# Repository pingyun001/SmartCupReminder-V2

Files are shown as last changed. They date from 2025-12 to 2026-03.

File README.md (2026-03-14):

<!-- 这是一张图片，ocr 内容为： -->
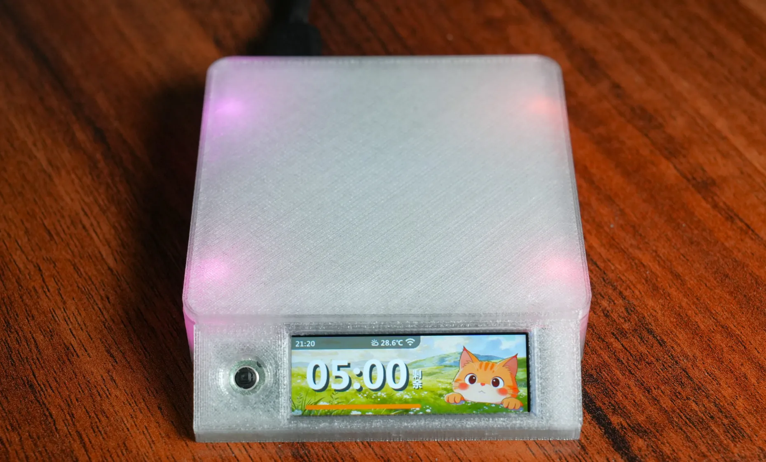
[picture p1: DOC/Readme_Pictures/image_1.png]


# 1、概览：
## 1.1、导览：
如果您拿到的是**成品杯垫**，直接查看章节1.概览、章节2开箱使用即可。无需查看其余章节。

如果您是电子爱好者，希望**从0开始动手制造**该杯垫，请阅读其余部分。

## 1.2、功能概览：
基础功能：

+ 放下水杯，杯垫自动进行一定时间倒计时，时间到，提醒用户喝水
+ 放下水杯、时间到了、拿走水杯 等语音播报
+ 可调节倒计时时间、灯光亮度、声音大小、灯光效果
+ 丰富的RGB灯光效果，支持 彩虹、蜡烛、星夜、纯白 四种灯效
+ 夜间模式，晚11点到早7点之间自动降低屏幕亮度和灯光亮度
+ 杯垫内集成温度传感器，可监测自身温度
+ 支持模拟U盘，可方便地更新语音文件（WAV文件）或更新固件（update.bin文件）

wifi联网功能：

> 本杯垫集成了wifi功能，可连接网络，实现时间自动同步和天气信息自动同步
>

+ 可连接指定2.4G wifi网络（需通过U盘模式 在setting.txt中存入wifi名称和密码）
+ 可指定当前城市，支持拼音（需通过U盘模式 在setting.txt中存入城市，例如北京：beijing）
+ 可自动获取当前城市的天气，温度，湿度，以及未来两天的天气预报
+ 可自动获取网络时间（24小时制）
+ 语音拓展功能：
    - 可根据当前时间，自动连携播放时间语音（早、中、晚）
    - 可根据当前天气，自动连携播放天气语音（晴天、下雨、下雪）

# 2、开箱使用
## 2.1、外观介绍
+ 摇杆：可向上下左右拨动，以及向中心按下，共5个方向。具体含义如下：
    - 上下左右：灵活切换各界面，选择选项卡等
    - 中：选择
+ 彩色屏幕：
    - 可显示倒计时时间、天气预报、设置等
+ 水杯放置区域：
    - 用于放置水杯，可被水杯的重量轻微下压1mm。
    - <font style="color:#DF2A3F;">注意！</font>整体材料为3D打印材料，怕热，请勿让水杯放置区域温度高于50℃
+ USB-TypeC接口：
    - 杯垫不含电池，需通过该接口供电，推荐供电能力5V 1A
    - 该接口同时作为USB通讯接口，可将杯垫通过该接口+数据线连接电脑后，在杯垫设置中打开U盘模式，即可更新杯垫内wifi密码、语音等。

<!-- 这是一张图片，ocr 内容为： -->
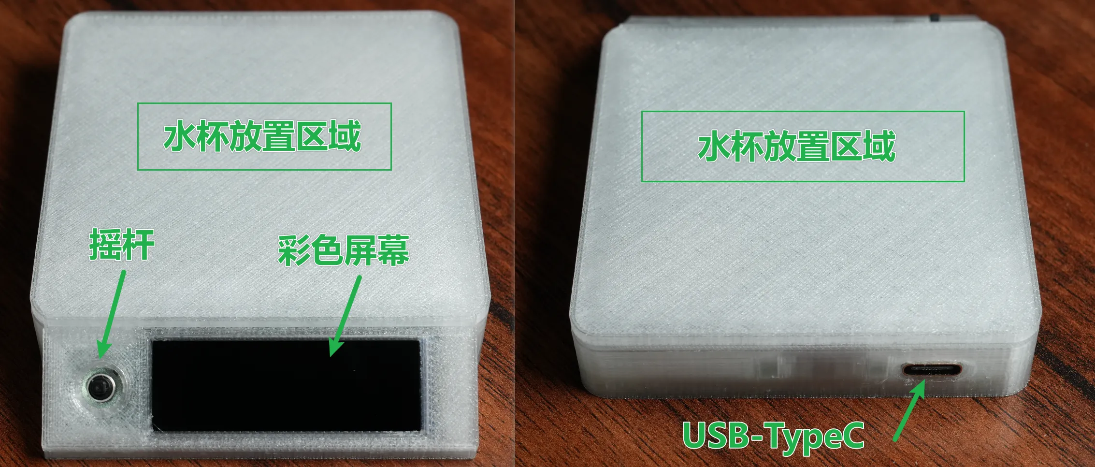
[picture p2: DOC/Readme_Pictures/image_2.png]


## 2.2、界面说明
### 2.2.1、开机自检界面
通过使用TYPE-C数据线连接USB-TypeC接口和电脑，杯垫屏幕点亮，并展示当前初始化进度：

<!-- 这是一张图片，ocr 内容为： -->
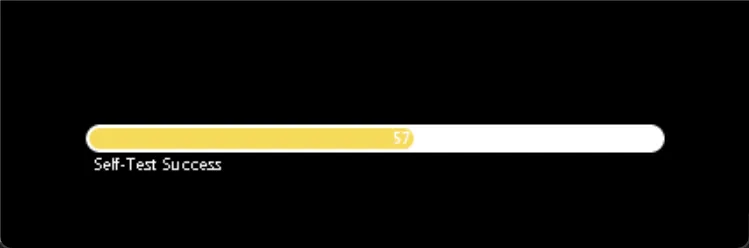
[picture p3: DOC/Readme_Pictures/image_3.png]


其中进度条展示当前开机进度，下方文字展示对应系统自检内容，如果进度条卡死，可根据下方自检内容判断故障原因。

### 2.2.2、主界面
自检完成后，进入主界面，可以看到如下信息：

> **<font style="color:#DF2A3F;">注！标星号*项需要wifi联网使用</font>**
>

+ 网络时间*：当前时间，可在连接wifi后自动通过网络获取
+ 夜间模式：用于指示当前杯垫是否处于夜间模式，该模式下屏幕和灯光亮度减弱
+ 天气信息*：该图标用于指示是否成功连接天气服务器，若成功连接，则该图标显示，否则隐藏
+ 杯垫温度：该温度由杯垫内部的温度传感器获取
+ wifi状态*：用于指示wifi是否成功连接，成功连接为白色，否则为黄色
+ 剩余时间进度条：用于指示剩余时间占总时间的比例
+ 剩余时间：用于显示剩余时间（格式  分钟：秒）
+ 杯垫状态：共三个表情包，分别对应 无水杯、水杯放下、时间到

<!-- 这是一张图片，ocr 内容为： -->
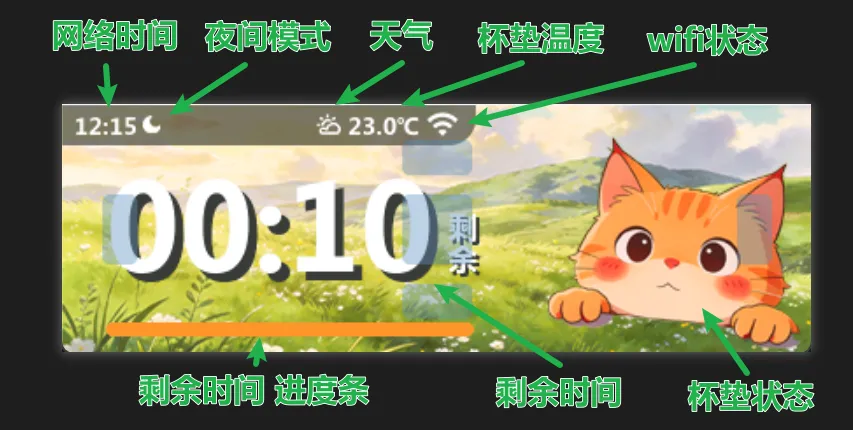
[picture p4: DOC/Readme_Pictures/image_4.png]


---

### 2.2.3、天气界面
在主界面下，可通过摇杆上划，进入天气界面：

> 注！该界面所有内容需联网使用
>

+ 当前城市*：中文显示城市名称，该中文名称由天气服务器返回
+ 今天、明天、后天：指示三天的日期，天气，温度范围，湿度

<!-- 这是一张图片，ocr 内容为： -->
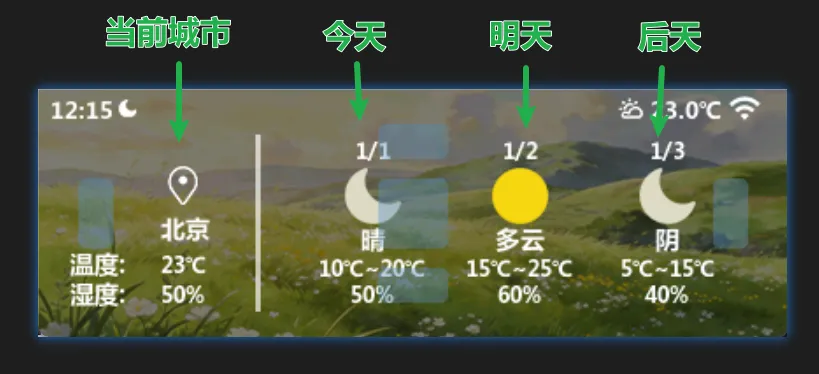
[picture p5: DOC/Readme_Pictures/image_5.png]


### 2.2.4、设置界面
在天气界面，继续上滑（或从主界面下滑，进入设置界面）：

设置界面中，可通过上下左右方向键选择需要的选项，并通过中键确定。左侧为标题，中间为具体选项，右侧为详细说明。

计时界面：

+ 可选择倒计时时间，当前固件支持如下6个常用时间

<!-- 这是一张图片，ocr 内容为： -->
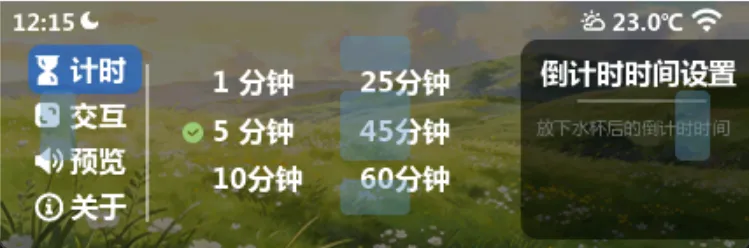
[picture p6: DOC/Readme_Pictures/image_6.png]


---

交互界面：

+ 可选择提示音大小
+ 可选择灯光亮度
+ 可选择灯光种类：
    - 虹：彩虹色效果，所有灯按彩虹色依次渐变过渡
    - 烛：模拟蜡烛效果，淡黄色灯光，亮度忽明忽暗
    - 星：星夜效果，4颗灯随机点亮，颜色随机
    - 白：纯白色效果，该模式灯光不闪烁。无动效

<!-- 这是一张图片，ocr 内容为： -->
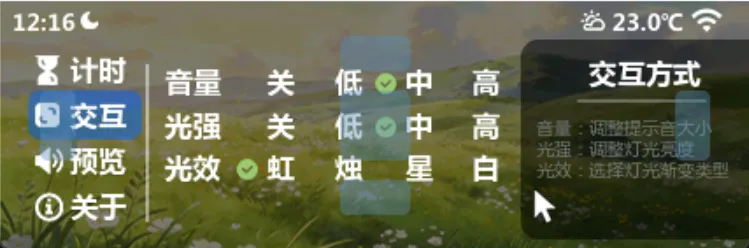
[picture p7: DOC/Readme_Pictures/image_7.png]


---

预览：

+ 用于预览存入杯垫内的音频文件，共有如下10种音频

<!-- 这是一张图片，ocr 内容为： -->
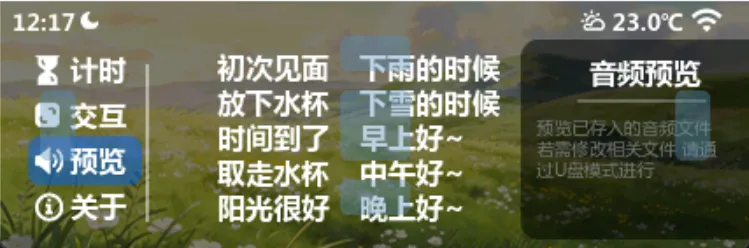
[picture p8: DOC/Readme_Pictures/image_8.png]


---

关于：

+ 可查看当前USB电压，若USB供电不足，会弹出相应提示框
+ JEDEC ID：为板载存储芯片的型号，用于辅助调试
+ WIFI IP：成功连接wifi后，显示杯垫的ip地址
+ 进度U盘 按钮：可将杯垫模拟成U盘，用于更新wifi信息等
+ 重置设备：谨慎操作！该选项会删除杯垫内所有数据（包括音频，字库等），用于杯垫发生极其严重的故障后使用。
+ 右侧 软件版本：显示当前程序的版本号，初始发行版本为V2.0。调试版本为V2.0 DEBUG
+ 右侧 编译时间：显示当前程序的编译时间，Feb 21 2026表示 编译于2026年2月21日

<!-- 这是一张图片，ocr 内容为： -->
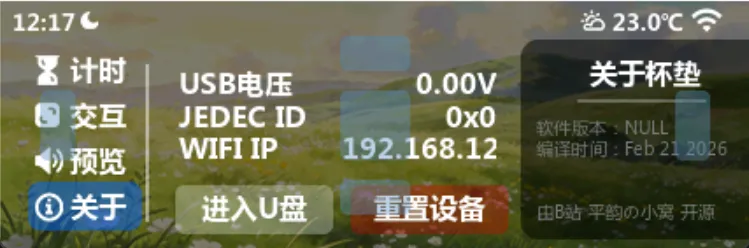
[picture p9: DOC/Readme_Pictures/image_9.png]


---

### 2.2.5、警告&错误
文件系统错误：

若初始化时进度条卡住，且弹出该提示框，表示内部存储芯片内文件损坏，5s后系统将进入U盘模式，可将必要文件拖入该U盘，待复制完成后，为杯垫断电，重新通电即可

<!-- 这是一张图片，ocr 内容为： -->
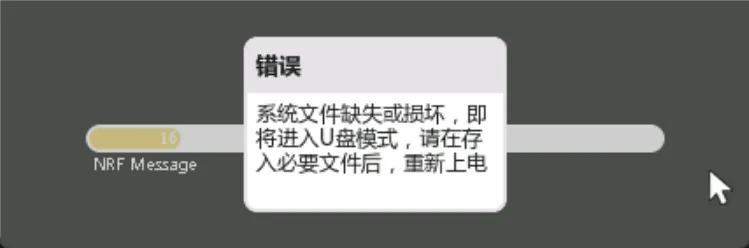
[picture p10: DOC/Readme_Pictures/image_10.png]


---

供电不足：

该提示框可能在任何时候弹出，一旦弹出，表示供电不足（系统会持续检测USB电压，在播放音频等大功耗工况时，可能导致USB电压过低，进而标记供电不足）。

推荐日常使用时，通过手机充电头供电，若使用电脑USB供电，且弹出该提示框，可适当降低音量或LED灯亮度。

<!-- 这是一张图片，ocr 内容为： -->
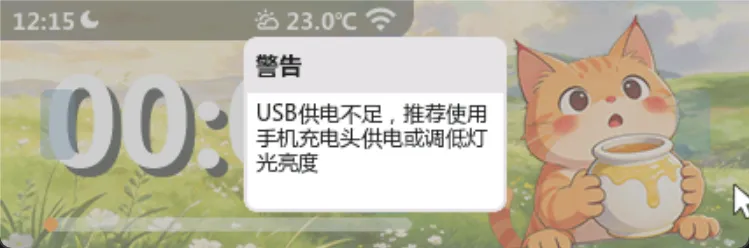
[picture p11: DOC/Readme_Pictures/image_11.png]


---

U盘模式提示：

在点击进入U盘按钮后，弹出该提示框。待提示框消失，即进入U盘模式（此时电脑应该会弹出 叮~ 的USB声音），同时杯垫屏幕、LED等均停止刷新。

在USB传输完成文件后，可在电脑上弹出U盘，之后推荐右滑摇杆，退出U盘模式。

注意！退出U盘模式后，建议断电 并重新上电，以使系统更新各类信息。

<!-- 这是一张图片，ocr 内容为： -->
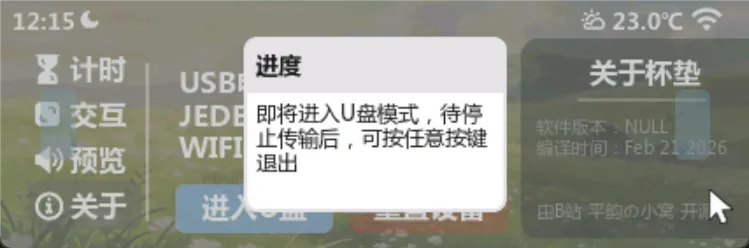
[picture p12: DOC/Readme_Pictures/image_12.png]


---

重置系统：

在点击重置设备按钮后，弹出该提示框。

<!-- 这是一张图片，ocr 内容为： -->
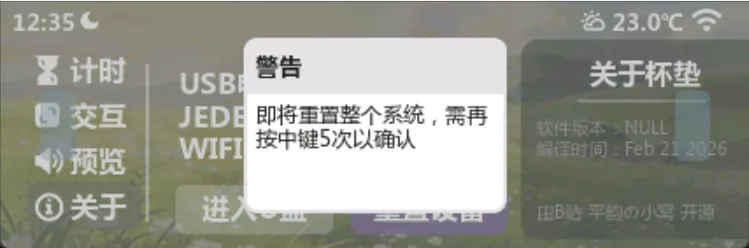
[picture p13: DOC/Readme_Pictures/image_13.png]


再次按5下中键，弹出第二个提示框，待该提示框消失，杯垫将删除所有用户文件（音频，配置信息等）

<!-- 这是一张图片，ocr 内容为： -->
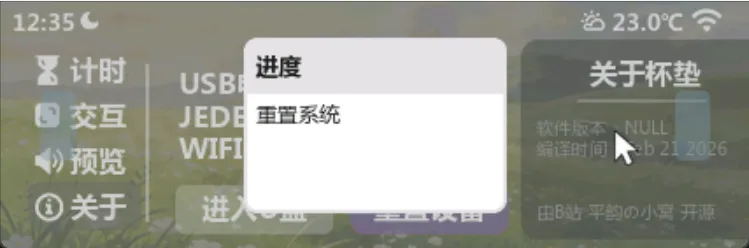
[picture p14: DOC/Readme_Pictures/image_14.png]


## 2.3、修改WIFI信息&连接网络
将杯垫通过USB线连接电脑，点击设置界面中 进入U盘按钮：

<!-- 这是一张图片，ocr 内容为： -->
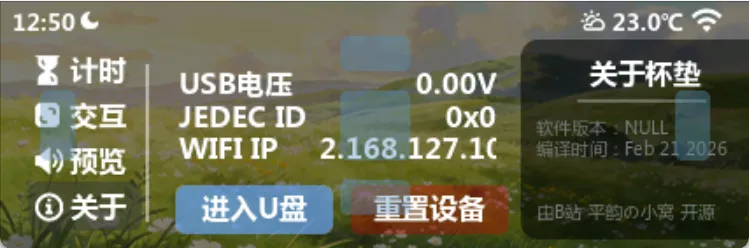
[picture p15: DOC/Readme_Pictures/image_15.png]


待提示框消失，打开电脑，可以看到多了一个U盘：

<!-- 这是一张图片，ocr 内容为： -->


打开该U盘，可以看到如下内容：

<!-- 这是一张图片，ocr 内容为： -->
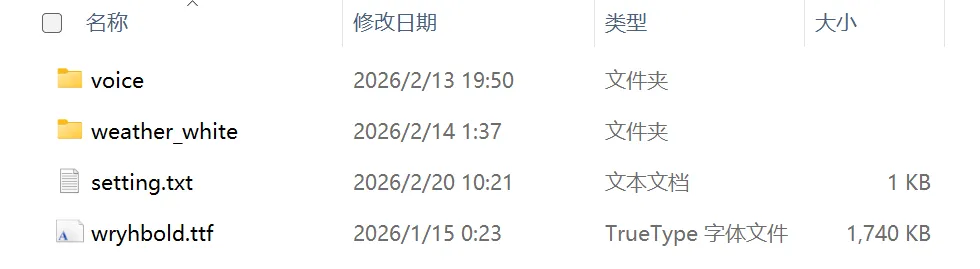
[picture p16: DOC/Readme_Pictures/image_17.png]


wifi信息等保存在setting.txt文件中，使用windows电脑自带的记事本打开该文件：

第一行为wifi名称，第二行为密码，第三行为城市名字

如下图所示，当前信息为：

+ wifi名称：TP-Link-1234
+ wifi密码：12345678
+ 城市名称：Beijing

<!-- 这是一张图片，ocr 内容为： -->
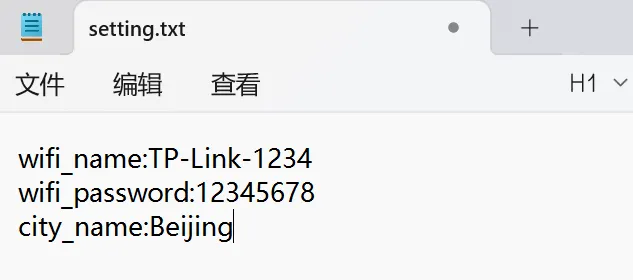
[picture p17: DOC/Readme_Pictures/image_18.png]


按需修改上述信息，

注意！

+ 请勿删除冒号:之前的字符！
+ 请保持每条信息均为新行，不可写到一行中！
+ wifi名称支持中文，需确保右下角编码格式为UTF-8编码

完成修改后，保存该setting.txt文件（可按键盘快捷吗Ctrl + S或记事本左上角 文件->保存）

保存后，从电脑端弹出U盘，为杯垫断电，重新通电，待重新开机，等待30秒左右，杯垫将成功连接wifi并更新天气信息。

## 2.4、更新固件
> 杯垫内置了bootloader，可自动识别Flash中的新固件并完成自动更新。该功能适用于定制主题固件的更新

请进行如下操作：
1. 确保杯垫软件版本号为V2.1及以后版本，若为V2.0，请参考3.5章节烧录二合一固件
2. 通过设置使杯垫进入U盘模式
3. 在路径 SmartCupReminder-V2\SOFTWARE\RELEASE_FIRMWARE下寻找你心仪的固件，该固件文件后缀必须为.bin格式
4. 将心仪固件，重命名为update.bin，并放入杯垫的U盘中，等待文件传输完成（大约1分钟，较慢，请耐心等待）
5. 杯垫断电，重新上电，待杯垫开机，杯垫将自动识别update.bin，若成功识别，左上角LED灯变为黄色，此时请等待杯垫完成固件更新
6. 大约2分钟后，更新完成，左上角LED灯变为绿色，杯垫完成固件更新，并自动删除update.bin文件，之后将自动运行新固件
7. 若中途失败，杯垫将亮红灯（或5分钟以上无响应），可重复上述步骤，若无效，请参考3.5章节通过BOOT按钮进行固件恢复

注意：
杯垫升级过程中，非必要尽量不要断电，以免造成损坏。（虽然bootloader中已经编写了完善的断电重更新机制，但是仍然建议不要随意断电）

# 3、复刻指南
本章节适用于从零制造的极客&电子爱好者，若您直接使用成品杯垫，可不看该章节。

## 3.1、获取工程
工程托管于GitHub：[https://github.com/pingyun001/SmartCupReminder-V2](https://github.com/pingyun001/SmartCupReminder-V2)

内含UI界面设计，硬件原理图，软件源码，机械结构等设计稿

推荐直接通过git克隆到本地即可。

如果电脑没有git环境，也可以直接下载压缩包：

<!-- 这是一张图片，ocr 内容为： -->
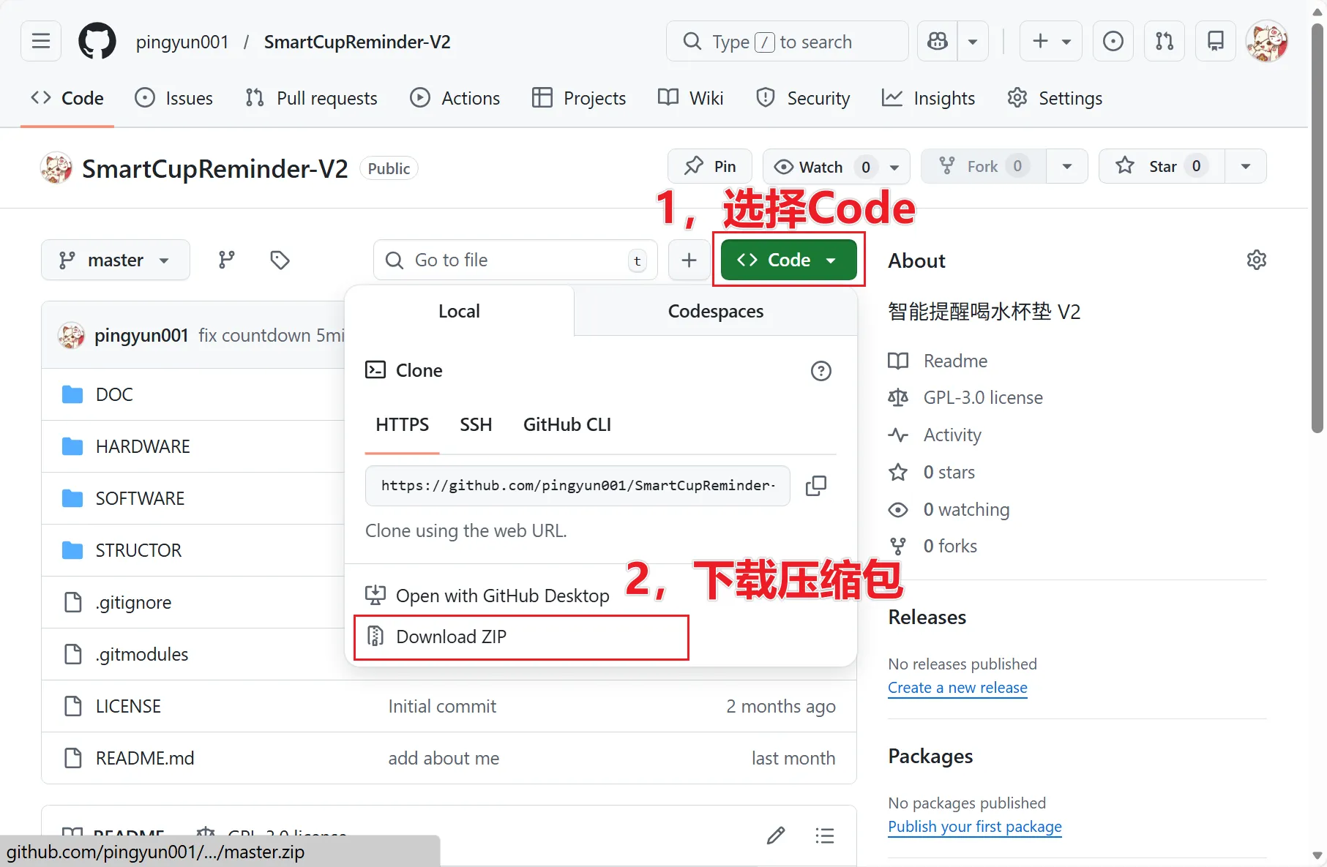
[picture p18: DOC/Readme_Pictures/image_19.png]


## 3.2、硬件焊接
> 默认您已经熟练掌握电路板下单，贴片元器件焊接等技能。
>

自行下单PCB板，注意板厚1.6mm，并完成焊接，焊接完成成品如下：

<!-- 这是一张图片，ocr 内容为： -->
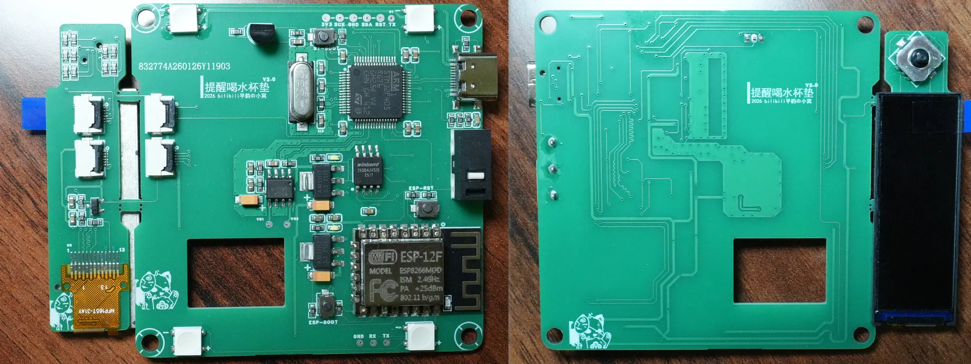
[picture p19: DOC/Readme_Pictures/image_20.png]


推荐优先焊接贴片原件，最后焊接屏幕。

屏幕焊接时，事先在屏幕背面贴好双面胶，并按如下方式对齐，粘贴后，弯折排线，完成焊接

<!-- 这是一张图片，ocr 内容为： -->
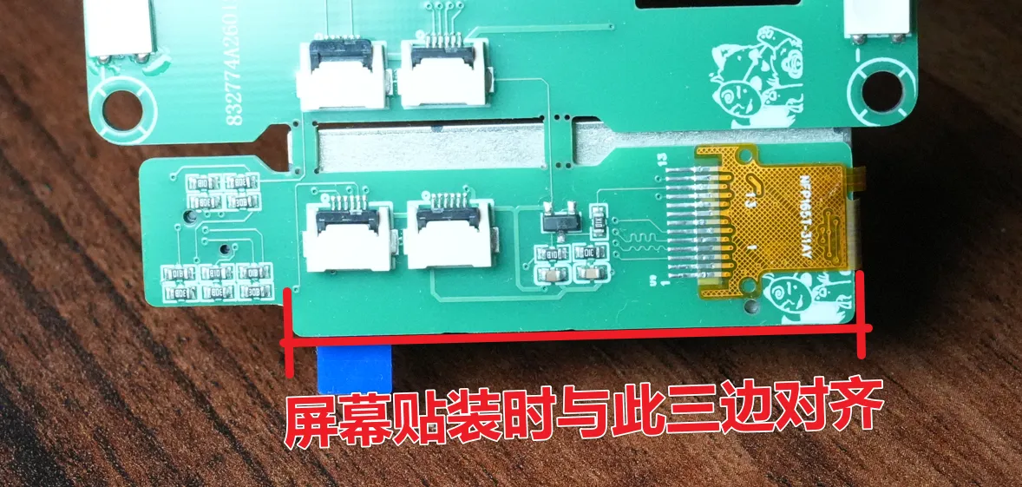
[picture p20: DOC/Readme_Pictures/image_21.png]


## 3.3、机械结构预组装
> 默认您已经熟练掌握3D打印，且有相关打印设备或条件
>

从工程中找到相关3D结构件并打印，共有三个结构件

> 位于路径：\SmartCupReminder-V2\STRUCTOR\打印件
>

推荐直接打印3MF后缀的三个文件
<!-- 这是一张图片，ocr 内容为： -->
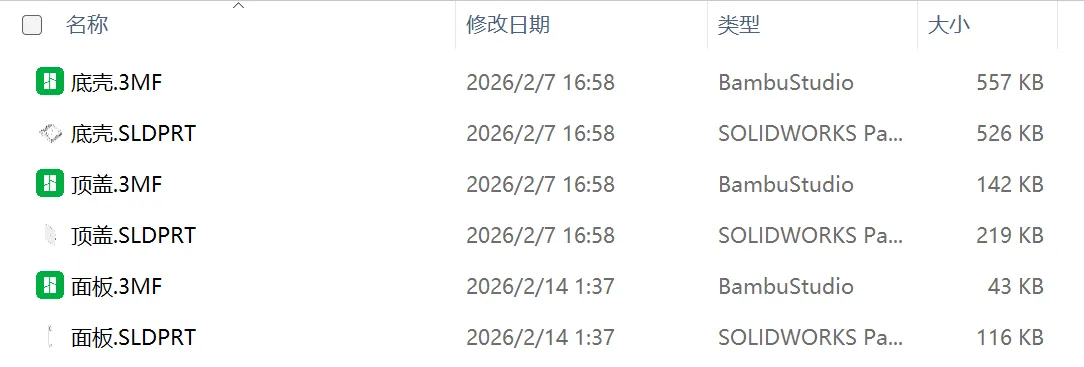
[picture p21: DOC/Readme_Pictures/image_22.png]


完成后如下：

<!-- 这是一张图片，ocr 内容为： -->
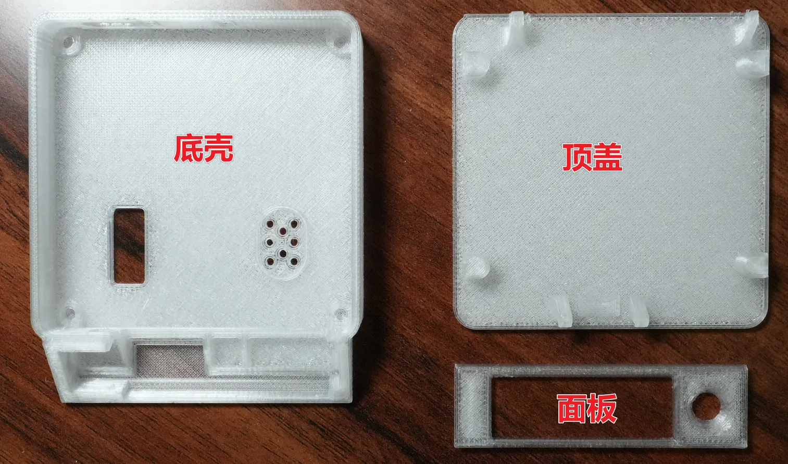
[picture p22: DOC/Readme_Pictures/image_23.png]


完成打印后，拆除必要的支撑，将PCB掰开（分离为底板和屏幕按键子板）后，

按如下步骤进行装配：

<!-- 这是一张图片，ocr 内容为： -->
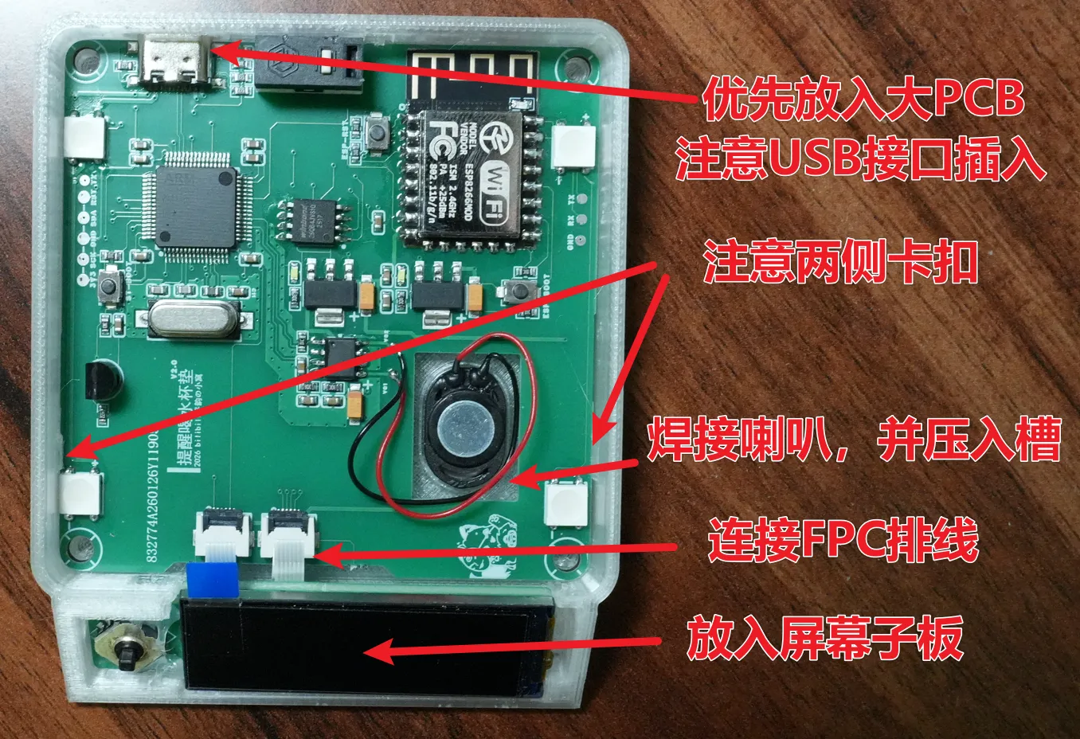
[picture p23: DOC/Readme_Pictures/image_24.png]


## 3.4、ESP8266固件下载
> 固件和源码均位于路径：SmartCupReminder-V2\SOFTWARE\ESP8266_WIFI_WEATHER

可通过传统arduino IDE下载，或通过ESP Tools下载，网上教程非常多，此次不过多介绍。

特别注意！建议使用CH340或CP2102等硬件USB转串口模块进行程序下载。不要使用ST-Link等软件模拟的串口。

按住ESP-BOOT后，为PCB上电，连接ESP下载串口，下载固件即可。

<!-- 这是一张图片，ocr 内容为： -->
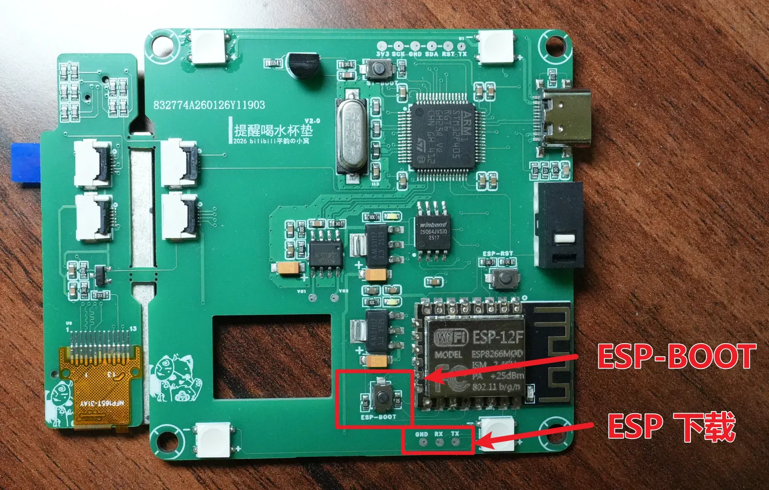
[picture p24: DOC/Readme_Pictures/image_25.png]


## 3.5、STM32固件烧录
> 固件位于路径：SmartCupReminder-V2\SOFTWARE\RELEASE_FIRMWARE

推荐电脑安装STM32CubeProgrammer软件：

<!-- 这是一张图片，ocr 内容为： -->
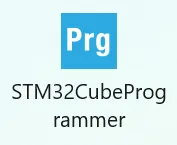
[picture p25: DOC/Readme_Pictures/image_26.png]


并烧录二合一固件Hex，该Hex中已经合并了Bootloader和App固件，无需单独烧录Bootloader。

> 固件位于路径SmartCupReminder-V2\SOFTWARE\RELEASE_FIRMWARE\V2.1\F405_Release_Merged.hex

<!-- 这是一张图片，ocr 内容为： -->
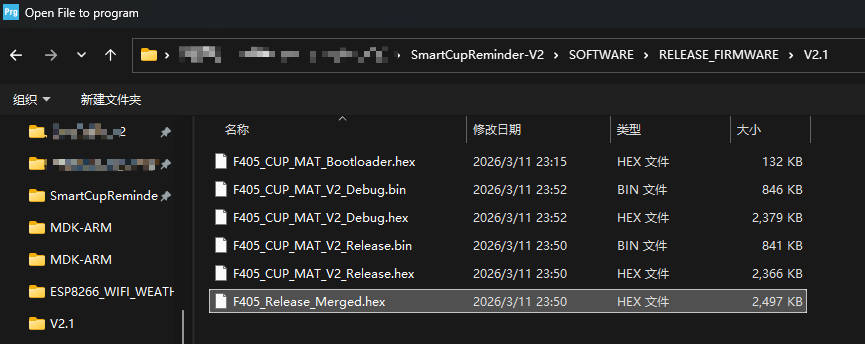
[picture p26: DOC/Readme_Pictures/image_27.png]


推荐使用USB数据线连接PCB板和CubeProgrammer软件，如下图，保持按住BOOT按钮，插入数据线到电脑

<!-- 这是一张图片，ocr 内容为： -->
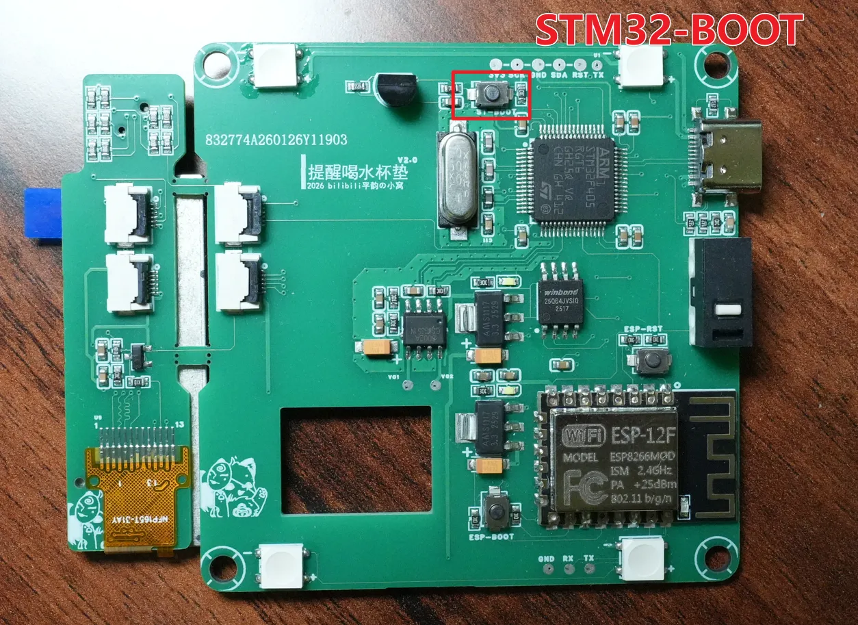
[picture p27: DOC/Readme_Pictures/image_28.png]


可以在CubeProgrammer软件中搜索到STM32芯片，搜索到后，点击连接按钮。

<!-- 这是一张图片，ocr 内容为： -->
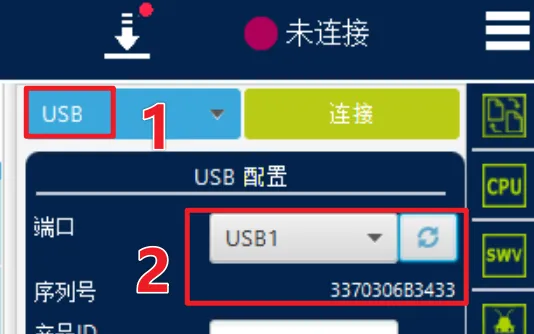
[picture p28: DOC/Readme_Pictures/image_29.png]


成功连接后，下图1处显示已连接，在2处选择上述Hex文件，并点3 开始烧录

<!-- 这是一张图片，ocr 内容为： -->
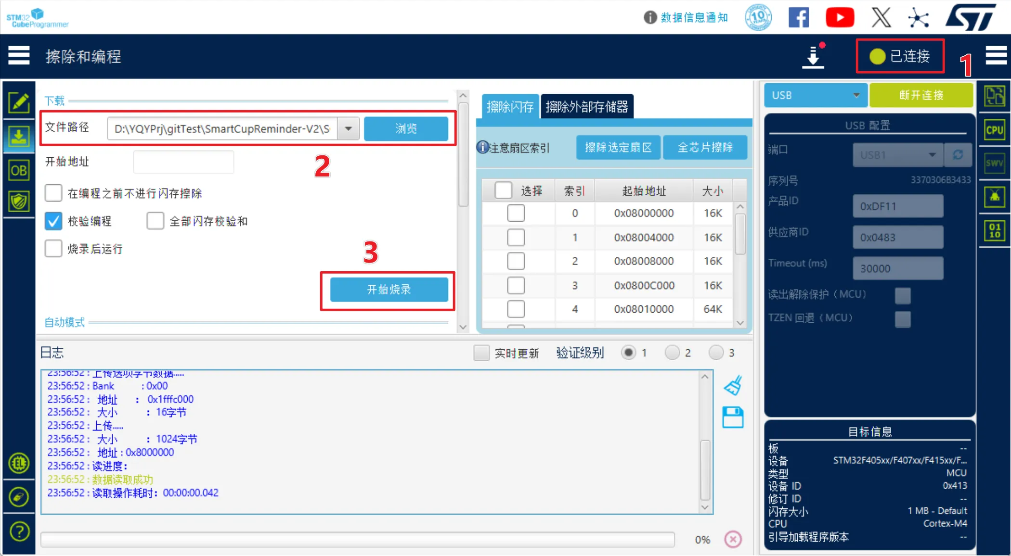
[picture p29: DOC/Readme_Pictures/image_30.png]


待进度条跑完即可。

如果USB方式无法下载，则需通过ST-Link、JLink等，通过SWD接口进行下载

> 由于STM32F4系列芯片的USB IP缺陷，以及板子USB焊接质量问题，可能有概率无法通过USB DFU连接（电脑弹出未识别的USB设备提示框），此时需要通过SWD接口下载程序
>

SWD接口位置如图，按线序连线即可，并连接板子，后续操作步骤同USB

连接ST-Link SWD接口到PCB板，推荐按如下方式接线：

左侧为ST-Link接口，右侧为PCB接口：
- 3V3   <---> 3V3
- SWCLK <---> SCK
- GND   <---> GND
- SWDIO <---> SDA
- RESET <---> RST

同时，建议断开USB供电，全板仅通过ST-Link提供STM32F4所需的3.3V电源

完成连接后，将ST-Link插入电脑，打开STM32CubeProgrammer软件，选择ST-Link模式，点击Connect按钮，选择下载的固件文件，点击Program按钮，等待下载完成。

<!-- 这是一张图片，ocr 内容为： -->
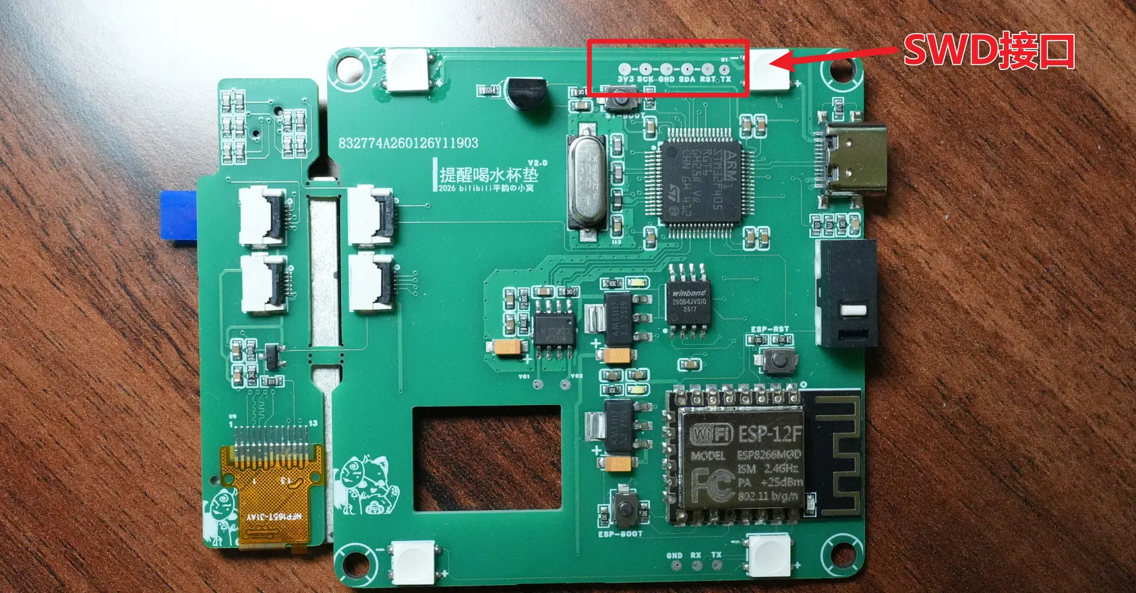
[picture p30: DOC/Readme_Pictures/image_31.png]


## 3.6、U盘文件下载
完成ESP8266和STM32固件烧录后，使用USB线连接杯垫和电脑，杯垫会进行开机自检，检测到文件缺失，会进行弹窗，并进入U盘模式

<!-- 这是一张图片，ocr 内容为： -->


此时电脑上会识别到一个U盘，将必要的文件复制入U盘中：

> 位于路径：SmartCupReminder-V2\SOFTWARE\F4_UDISK_RESOURCES
>

该路径共有如下文件/文件夹，含义：

+ voice：必要的音频文件，格式为WAV
+ weather_white：天气小图标文件，用于天气界面的图片显示
+ setting.txt：用于保存wifi名称，wifi密码，城市位置
+ wryhbold.ttf：中文字体库文件，用于UI界面中的中文显示（城市名称等）

<!-- 这是一张图片，ocr 内容为： -->
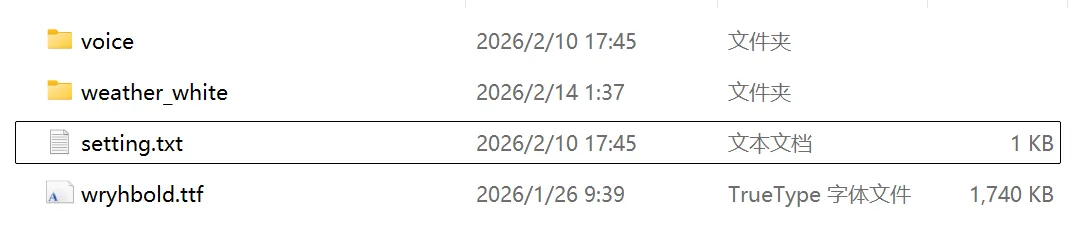
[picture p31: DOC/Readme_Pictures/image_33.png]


其中setting.txt中的内容需要根据自己的wifi名称进行修改，可参考2.3章节。

将这些文件/文件夹全部复制到U盘根目录，完成后，弹出U盘，断电，重新上电，等待自检完成。

成功进入主界面

<!-- 这是一张图片，ocr 内容为： -->
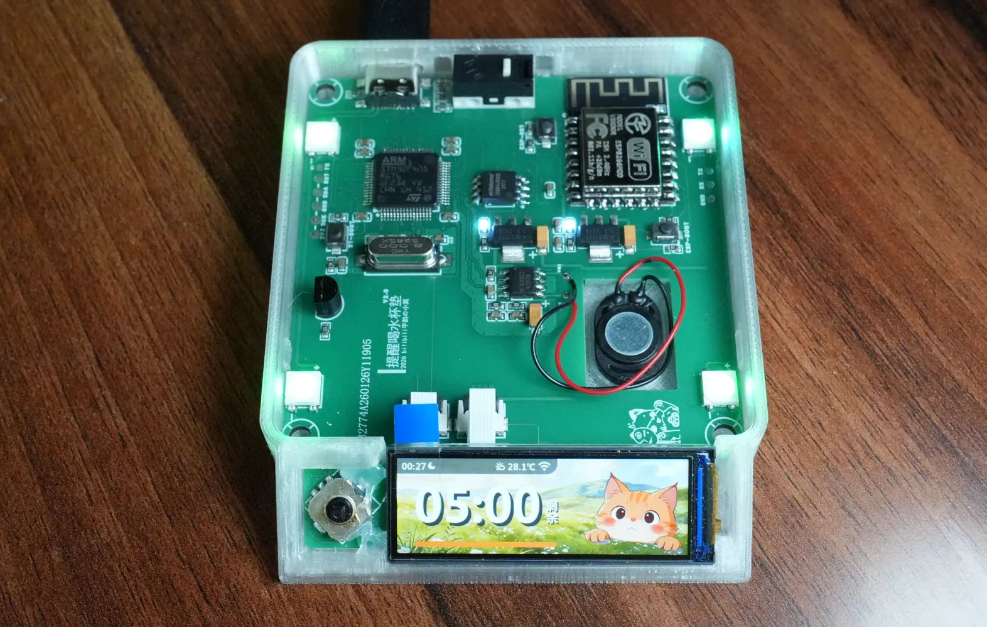
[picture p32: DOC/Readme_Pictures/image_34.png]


## 3.7、机械结构组装
在之前的基础上，安装顶盖：

<!-- 这是一张图片，ocr 内容为： -->
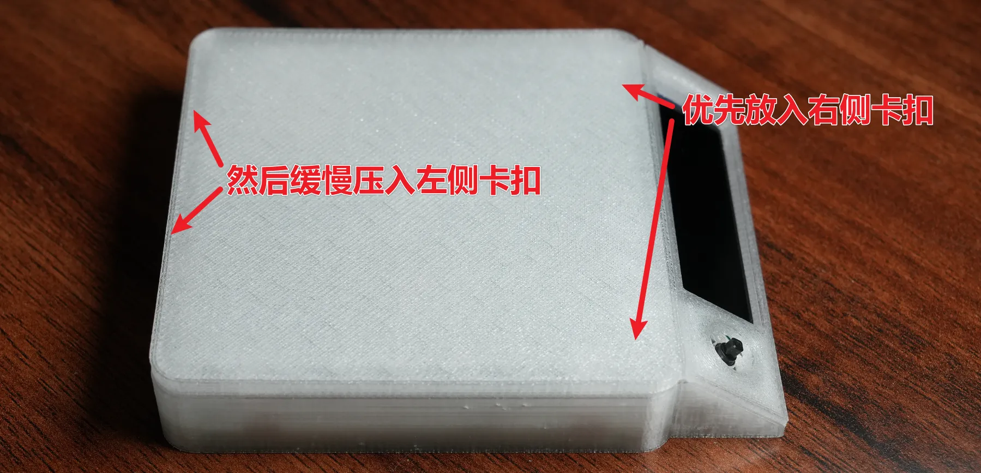
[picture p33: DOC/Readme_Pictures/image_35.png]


同时使用热熔胶粘贴前面板，并完成制作。

此时，您已经成功获取到一个成品杯垫！恭喜~

## 3.8、后续固件升级
> 杯垫内置了bootloader，可自动识别Flash中的新固件并完成固件更新。该功能适用于定制主题固件的更新，以及切换debug和release版本固件。

请进行如下操作：
> 注意！只适用于目前运行V2.1及以上版本固件的杯垫，如果您的杯垫目前运行V2.0版本，则需要手动更新固件，参考上方3.5章节烧录二合一固件。

固件类型说明：
U盘自动更新只支持后缀为.bin的文件，类型包含两种，分别为Debug版和Release版，均位于目录
> SmartCupReminder-V2\SOFTWARE\RELEASE_FIRMWARE\

- F405_CUP_MAT_V2_Debug.bin：包含调试信息（包含屏幕帧率，CPU占用率，串口日志等，可能会轻微影响性能，仅供调试使用）
- F405_CUP_MAT_V2_Release.bin：无调试信息（日常使用版）

自动更新流程：

1. 寻找心仪的固件（固件列表里后缀为.bin的文件，若您的电脑未显示文件后缀，请查看本文结尾），将其改名为update.bin，并记住位置 
2. 进入U盘模式，将需要更新的固件文件（update.bin）放入U盘根目录，待传输完成后，弹出U盘
3. 为系统重新上电，等待左上角LED灯点亮
4. 若LED为黄色，则成功识别到待更新固件，并开始尝试更新，
5. 若更新成功，则LED灯变绿色，之后系统会自动运行新固件

# 4、系统架构浅析
## 4.1、硬件架构
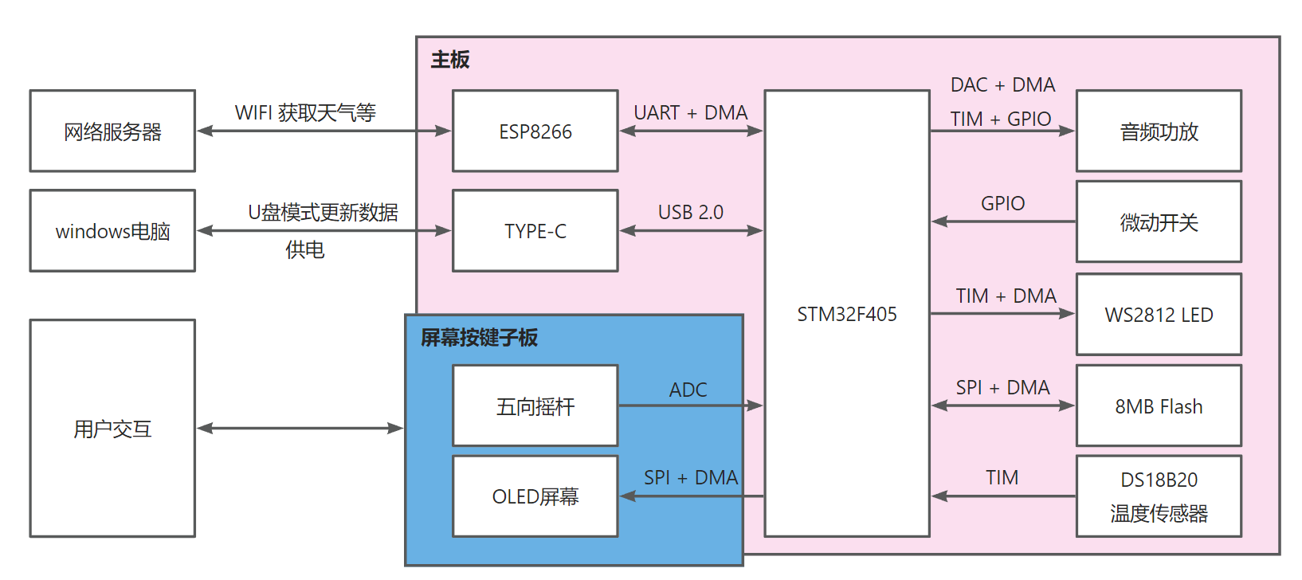
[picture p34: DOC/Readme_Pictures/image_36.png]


## 4.2、软件架构
主要使用技术栈：

+ FreeRTOS操作系统
+ LVGL V9.3图形库
+ FatFs文件系统
+ 前后端分离架构，GUI框架可直接在模拟器上运行，并无缝部署到硬件环境

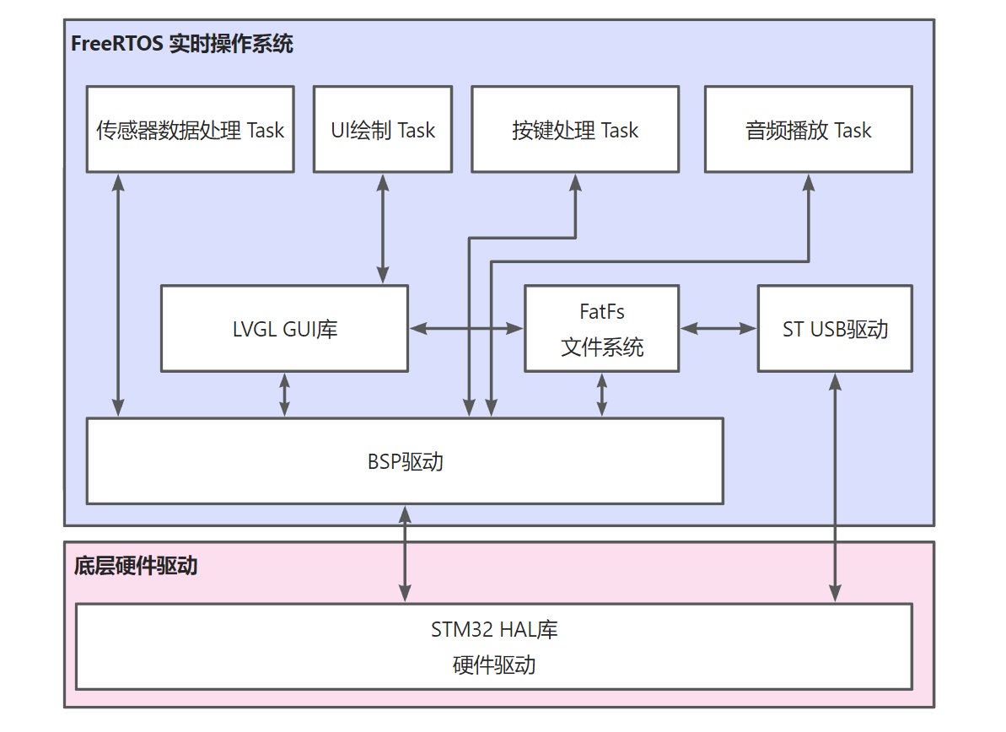
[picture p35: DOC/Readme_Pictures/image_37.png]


# 5、Q and A
## 5.1、有哪些素材可以自定义修改？
背景图片，三张表情图片，10条语音均可以进行替换。前者可用工程中附带的PS工程辅助导出相关图片，并通过LVGL Python图片工具导出对应的C数组，重新编译固件即可。后者可找任意AI配音网站，生成相应声音，并通过U盘模式替换即可。

注意！生成的音频素材需要使用格式工厂或ffmpeg等工具转换为WAV格式，并保持文件名不变，同时需确保如下参数：

- 采样率：22050Hz
- 位深：16bit
- 单声道
- 编码：PCM

## 5.2、不小心恢复出厂设置了咋办？
需要一台windows电脑，按上述**3.6章节**部分重新存入U盘文件即可

## 5.3、如何查看当前运行的固件版本？
在杯垫设置页面最后一页（关于页面）右侧，有软件版本，后接版本号为当前运行的版本。

<!-- 这是一张图片，ocr 内容为： -->


## 5.4、如何让电脑显示文件扩展名？
> 适用于win10和win11系统

<!-- 这是一张图片，ocr 内容为： -->
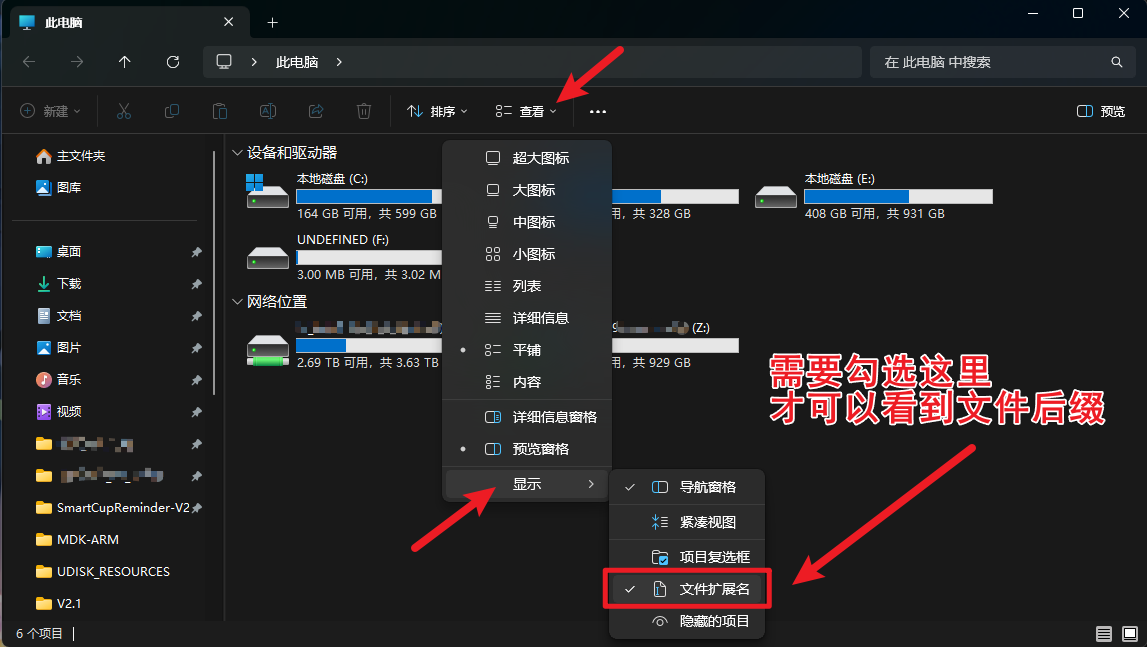
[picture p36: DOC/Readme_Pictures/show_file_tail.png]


然后打开固件目录，就可以看到文件拓展名了:

<!-- 这是一张图片，ocr 内容为： -->
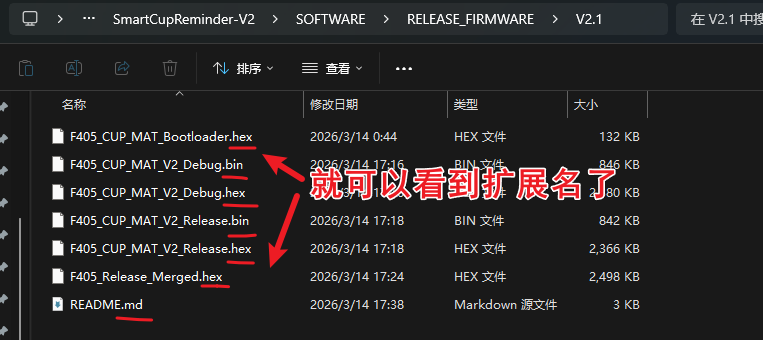
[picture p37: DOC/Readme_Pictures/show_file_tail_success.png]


# 6、版权
bilibili 平韵の小窝 原创作品

仅限个人学习使用，严禁无授权的商业用途！

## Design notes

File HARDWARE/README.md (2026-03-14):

# 文件夹概览

- SCH：提醒喝水杯垫原理图
- PCB：提醒喝水杯垫PCB图以及交互式焊接BOM表、PCB Gerber文件

# 原理图说明
## 系统硬件架构
画板

## 关键芯片选型
- MCU：STM32F405RGT6（192KB SRAM， 1MB Flash）
- 功放：FM8002A（DAC + DMA直推）
- 无线：ESP8266（UART）
- 存储：W25Q64JV（8MB SPI接口驱动）
- 屏幕：NV3007（142 * 428像素 SPI接口）
## 原理图
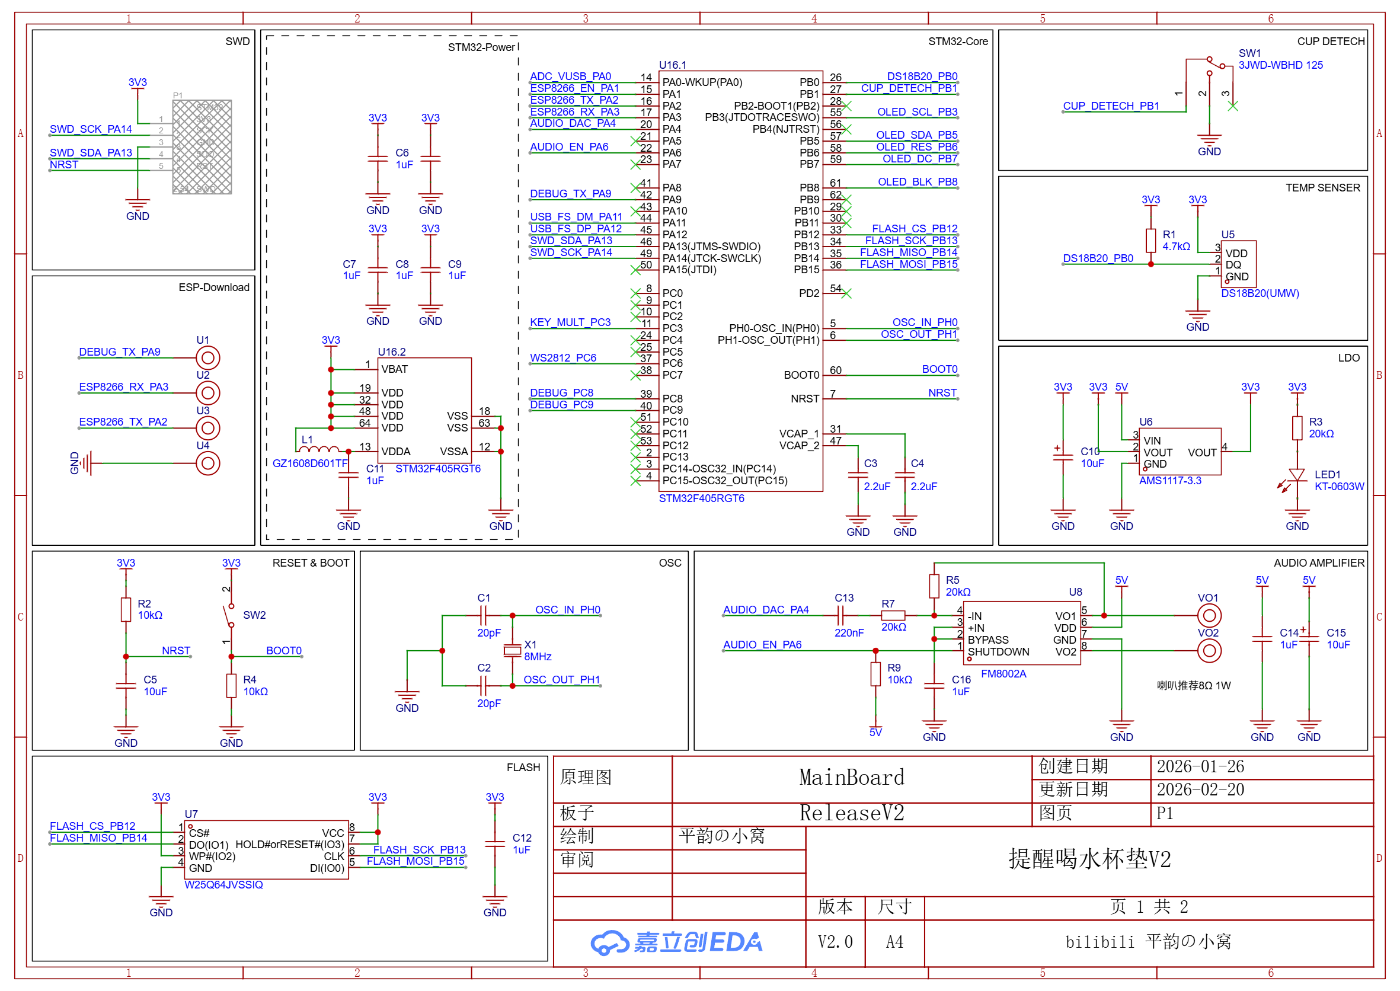
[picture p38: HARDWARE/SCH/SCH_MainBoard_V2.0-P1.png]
原理图V2.0-P1

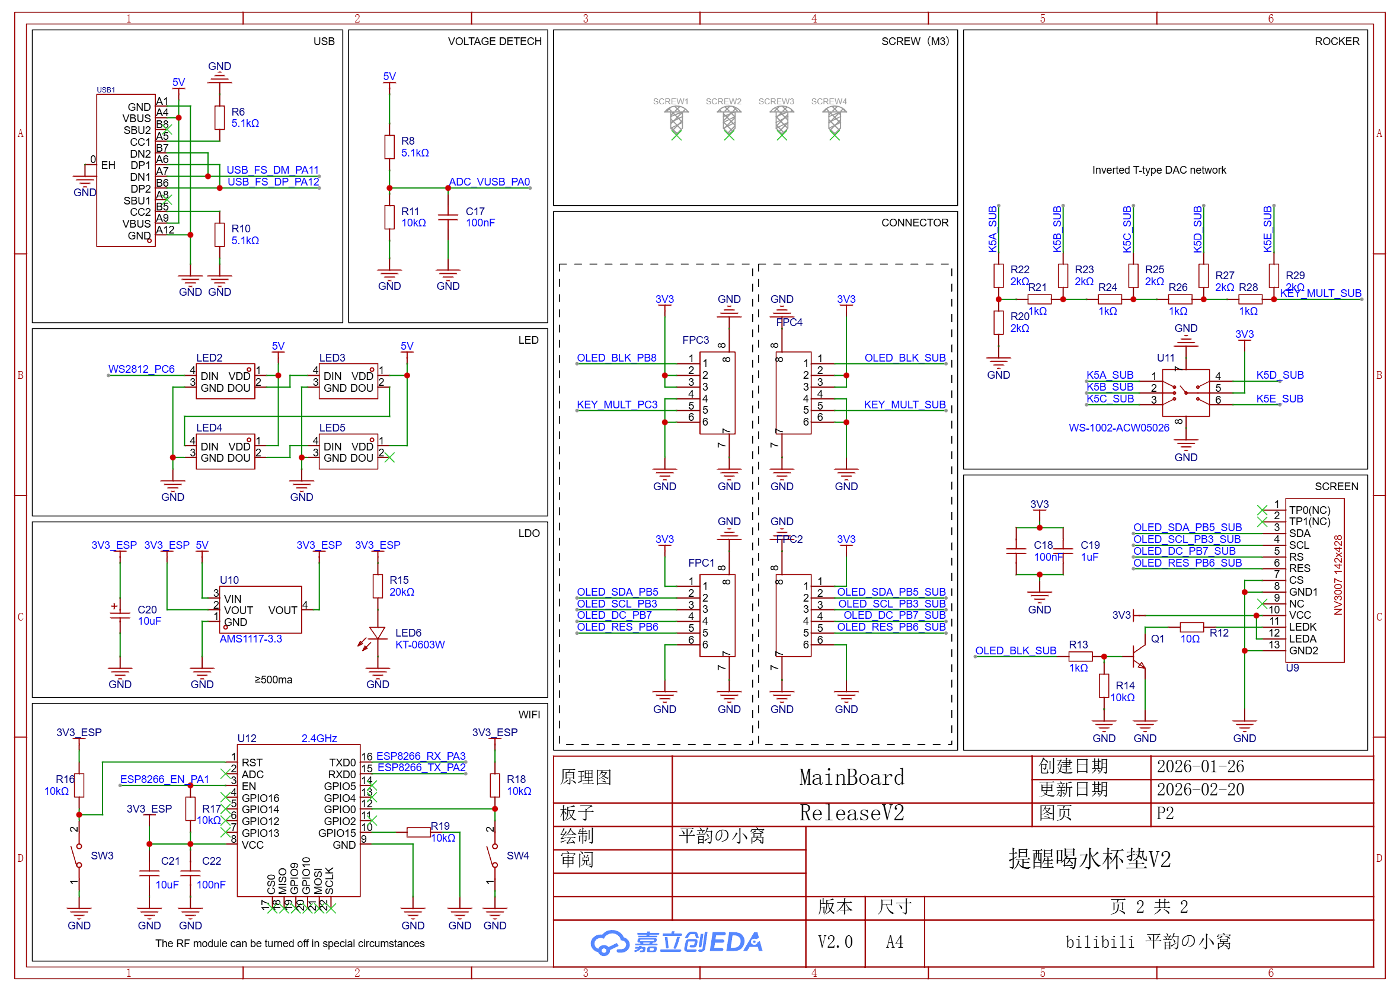
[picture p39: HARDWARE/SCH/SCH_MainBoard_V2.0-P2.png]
原理图V2.0-P2


# PCB说明
推荐制作工艺：
- 两层板
- 板厚1.6mm
- 无需沉金工艺

## PCB 裸板
<div style="text-align: center;">
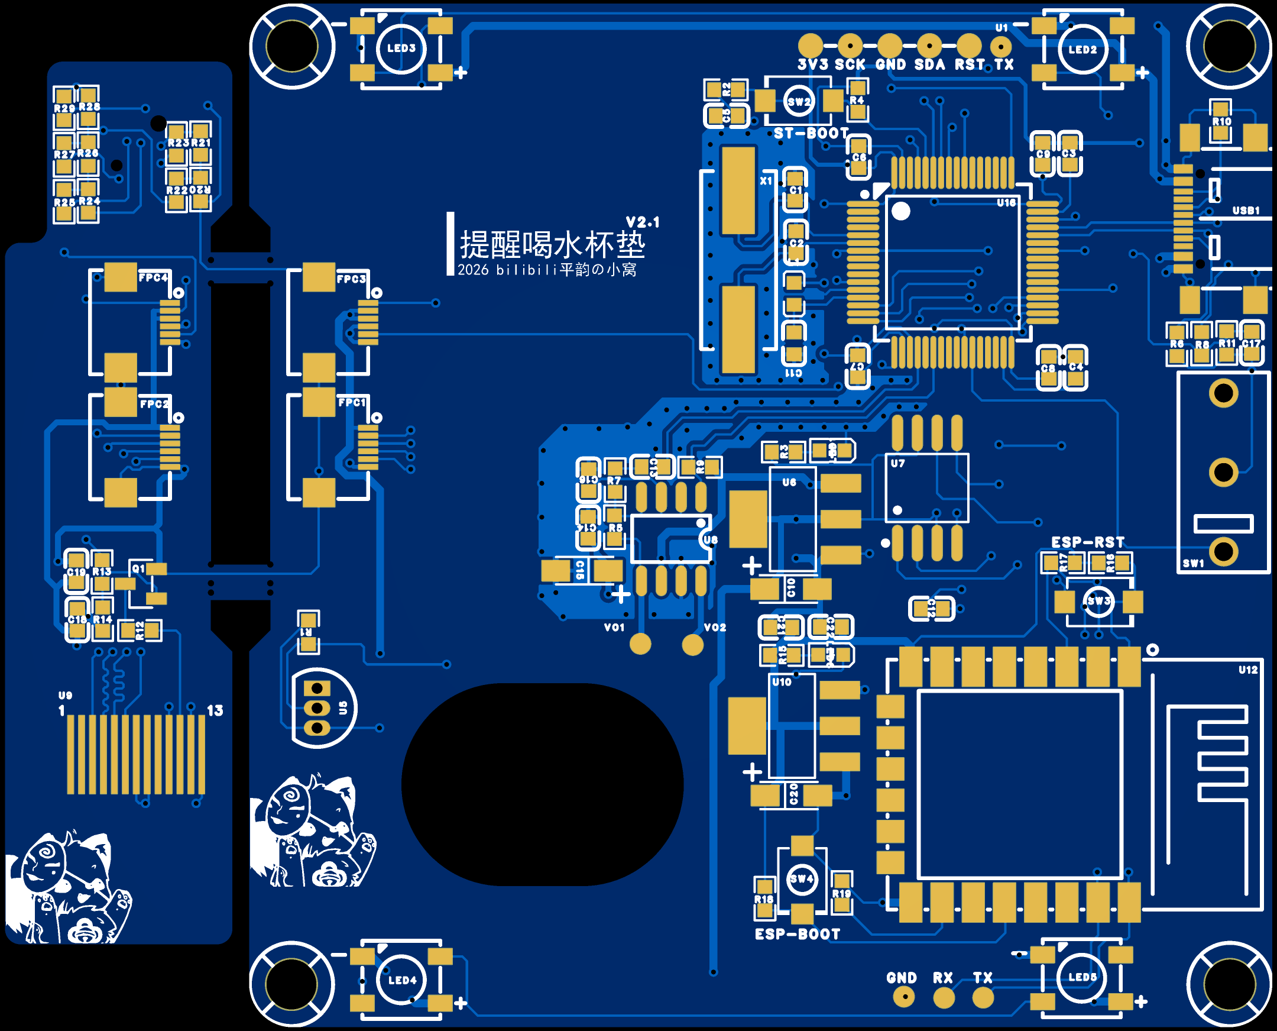
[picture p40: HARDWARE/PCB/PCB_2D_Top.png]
  
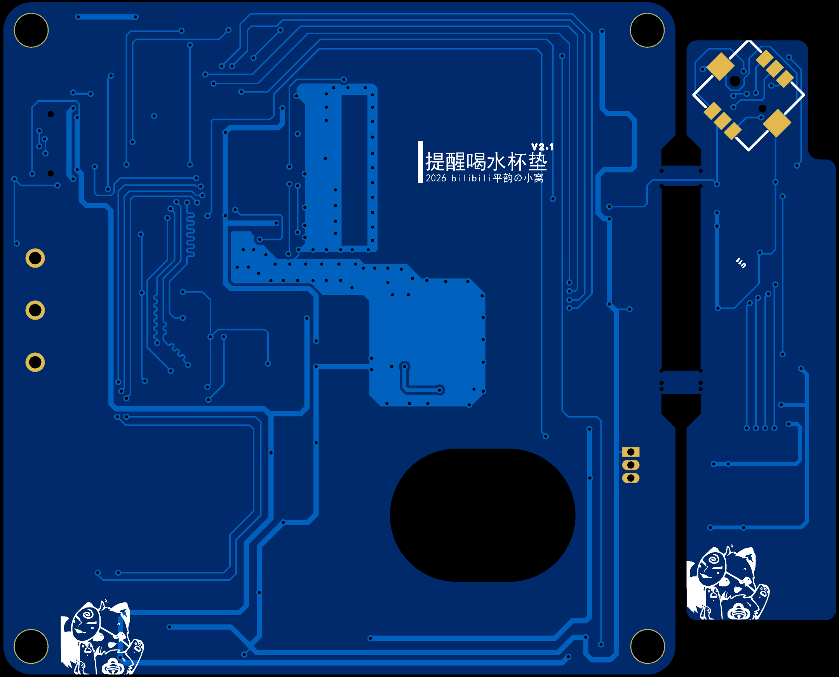
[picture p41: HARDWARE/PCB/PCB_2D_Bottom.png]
  
</div>

## PCB 原件贴装
推荐焊接顺序：
1. 所有正面贴片原件
2. 除屏幕外，所有背面贴片原件
3. 直插原件（DS18B20温度传感器，微动开关）
4. 屏幕（注意屏幕背面需粘贴双面胶，且双面胶不耐热）
<div style="text-align: center;">
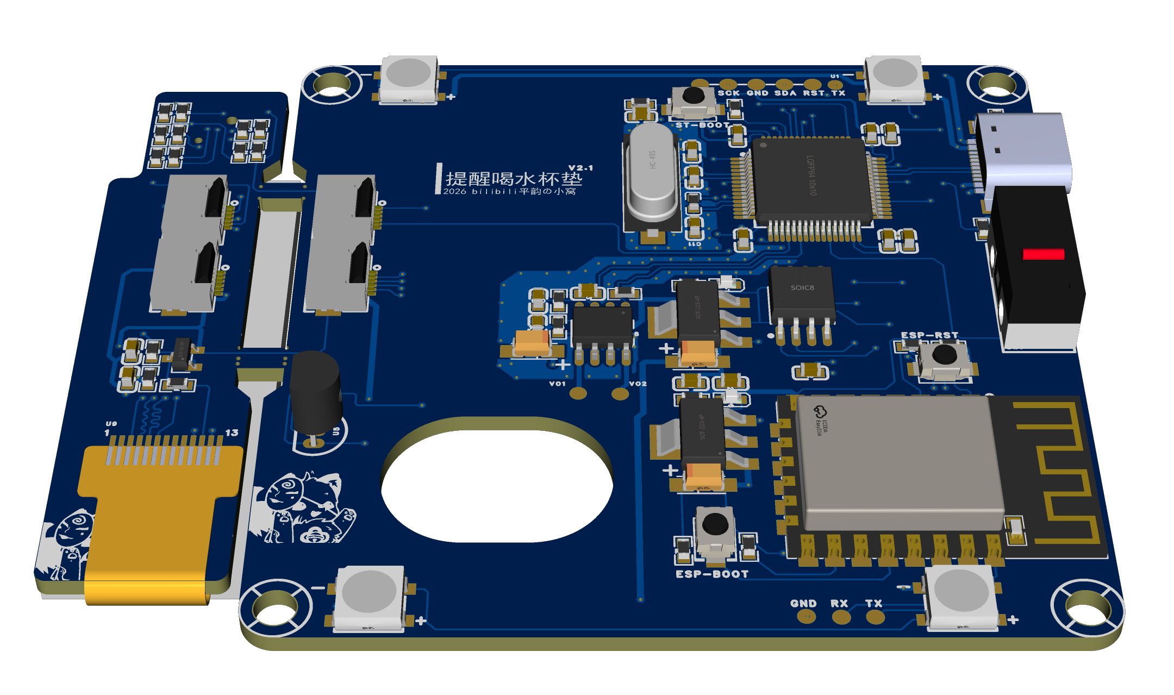
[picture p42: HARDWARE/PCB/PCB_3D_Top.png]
  
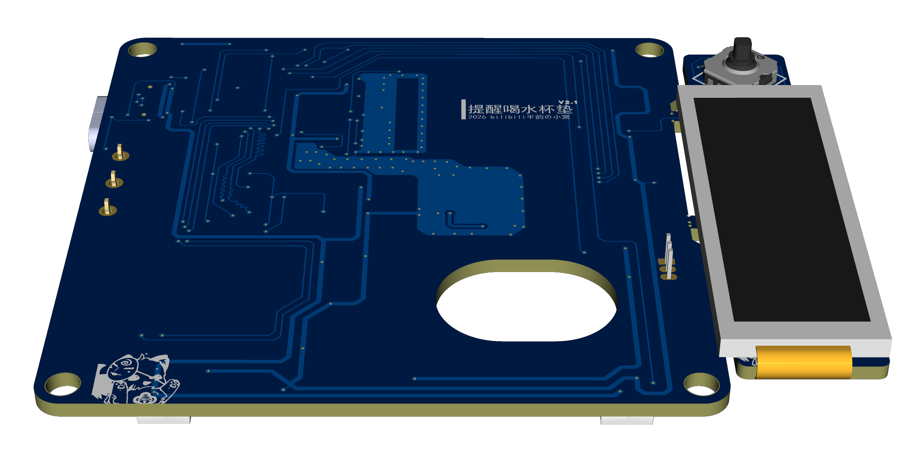
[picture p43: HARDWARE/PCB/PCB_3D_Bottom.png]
  
</div>

# 版权
bilibili 平韵の小窝 原创作品

仅限个人学习使用，严禁无授权的商业用途！

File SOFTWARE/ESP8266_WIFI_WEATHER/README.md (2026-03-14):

# 使用官方工具下载固件
PCB板使用USB TypeC接口供电，保持按住ESP-BOOT按键，然后短按一下ESP-RST按键，使ESP8266进入串口下载模式。

使用USB转串口工具连接 ESP8266下载串口，共如下三根线：
- GND
- TX
- RX

双击打开官方下载工具：

keil_download_firmware

按如下选择模组型号

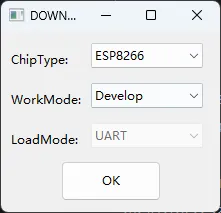
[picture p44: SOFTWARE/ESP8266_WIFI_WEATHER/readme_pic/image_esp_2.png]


按需选择自己的串口，固件bin，其余选项和下图一致

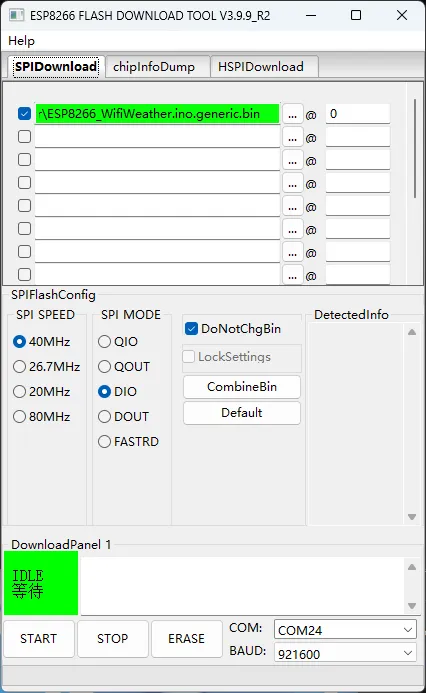
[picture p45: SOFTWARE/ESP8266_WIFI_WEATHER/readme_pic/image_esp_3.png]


选择正确后，点击START按钮，等待下载完成

# ESP8266代码说明

程序中使用了心知天气API来获取当前天气，使用阿里云API获取当前时间。

如二次开发，推荐替换心知天气密钥为自己申请的密钥：
```
#define WEATHER_API_KEY "这里放密钥"  // 替换为你的实际心知天气API密钥
```
程序开始运行后，需要通过串口发送三个参数到ESP8266：

- 位置：set_position:Beijing
- wifi名称：set_wifiname:tplink123456
- wifi密码：set_wifipasswd:400123456

ESP8266接收到参数之后，尝试自动连接WiFi，并获取心知天气信息，ESP8266日志如下：
```
Connecting to WiFi...
SSID: tplink123456
................
---WiFi connected:ok
---IP address:192.168.124.53
---Signal strength (RSSI):-55dBm
==================================
---nowtime:15:28:53
=== Current Weather Details ===
---City:北京
---Temperature:-4
Update Time: 2026-01-18T15:17:40+08:00
=== 3-Day Weather Forecast ===
---Date: 2026-01-18
---code_day:4
---Day:多云
---TemperatureLow:-11
---TemperatureHigh:-3
---Humidity:67
---end
---Date: 2026-01-19
---code_day:0
---Day:晴
---TemperatureLow:-13
---TemperatureHigh:-5
---Humidity:35
---end
---Date: 2026-01-20
---code_day:0
---Day:晴
---TemperatureLow:-13
---TemperatureHigh:-4
---Humidity:37
---end
=====================
```

这些日志信息会由STM32自动解析，并更新到GUI界面上

# 源码编译说明
> 非必要不建议编译源码，目前功能已经足够大部分用户使用。

源码使用arduino IDE编译，需要安装ESP8266库，并提前到心知天气官网申请API Key，将申请到的Key填入到源码中：
```
// ============ 用户配置区 ============
#define WEATHER_API_KEY ""  // 填入你申请的心知天气API密钥
```
尝试编译固件，并上传到ESP8266模组中，进行调试。

# 版权
bilibili 平韵の小窝 原创作品

仅限个人学习使用，严禁无授权的商业用途！

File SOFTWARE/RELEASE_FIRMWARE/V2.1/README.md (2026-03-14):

# V2.1 固件说明
新增bootloader + app功能，若非特殊说明，该bootloader适用未来所有版本固件
## 概述
芯片型号：STM32F405RG
- 固件起始地址：0x08010000

# 下载方式
推荐使用STM32CubeMX工具下载，可通过ST-Link或USB DFU下载。

## 方案1：U盘自动更新
> 该方案适用于所有运行在V2.1及以上版本固件的杯垫，旧版V2.0及以下版本固件不适用。

1. 寻找心仪的固件（固件列表里后缀为.bin的文件），将其改名为update.bin，并记住位置
2. 进入U盘模式，将需要更新的固件文件（update.bin）放入U盘根目录，待传输完成后，弹出U盘
3. 为系统重新上电，等待左上角LED灯点亮
4. 若LED为黄色，则成功识别到待更新固件，并开始尝试更新
5. 若更新成功，则LED灯变绿色，之后系统会自动运行新固件

## 方案2：ST-Link
> 该方案最为稳定，也是最推荐的方案，但是需要额外准备一个ST-Link调试器。

连接ST-Link SWD接口到PCB板，推荐按如下方式接线：

左侧为ST-Link接口，右侧为PCB接口：
- 3V3   <---> 3V3
- SWCLK <---> SCK
- GND   <---> GND
- SWDIO <---> SDA
- RESET <---> RST

同时，建议断开USB供电，全板仅通过ST-Link提供STM32F4所需的3.3V电源

完成连接后，将ST-Link插入电脑，打开STM32CubeProgrammer软件，选择ST-Link模式，点击Connect按钮，选择下载的固件文件（.hex后缀），点击Program按钮，等待下载完成。

## 方案3：USB DFU
> 该方案有概率失败（受限于USB线材质量，焊接质量，以及STM32F4系列众所周知的USB bug，有概率无法被电脑识别）

按住PCB上的ST-BOOT按键 不松开，通过USB-TypeC线连接PCB板和电脑，打开STM32CubeProgrammer软件，选择USB DFU模式，点击Connect按钮，选择下载的固件文件，点击Program按钮，等待下载完成。

# 版权
bilibili 平韵の小窝 原创作品

仅限个人学习使用，严禁无授权的商业用途！

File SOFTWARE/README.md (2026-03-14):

# 文件夹概览

- ESP8266_WIFI_WEATHER：ESP8266 Wifi天气小组件源码
- F405_BOOTLOADER：提醒喝水杯垫F405主板引导程序，使用Keil 5 MDK编写
- F405_CUP_MAT_V2：提醒喝水杯垫F405主板应用程序，使用Keil 5 MDK编写
- LVGL_SIMULATION：LVGL GUI界面代码以及对应的资源文件
- RELEASE_FIRMWARE：编译好的固件文件，可用于刷机或调试
- SIGNATURE_TOOLS：应用程序签名工具，可为新编译完成的应用程序签名，以便bootloader识别并自动更新
- UDISK_RESOURCES：提醒喝水杯垫主板U盘资源文件（需要自行拷贝到文件系统根目录中）

# MDK固件说明
## 固件阅读说明：
- 主板固件使用Keil 5 MDK编写，需要AC6编译器，推荐Keil版本V5.38及以上！
- 缩进为4，以方便阅读
- 主板固件源码中，有些地方可能有中文（LVGL界面相关），请注意不要修改文件编码格式（当前为UTF-8）

推荐按下图修改缩进方式
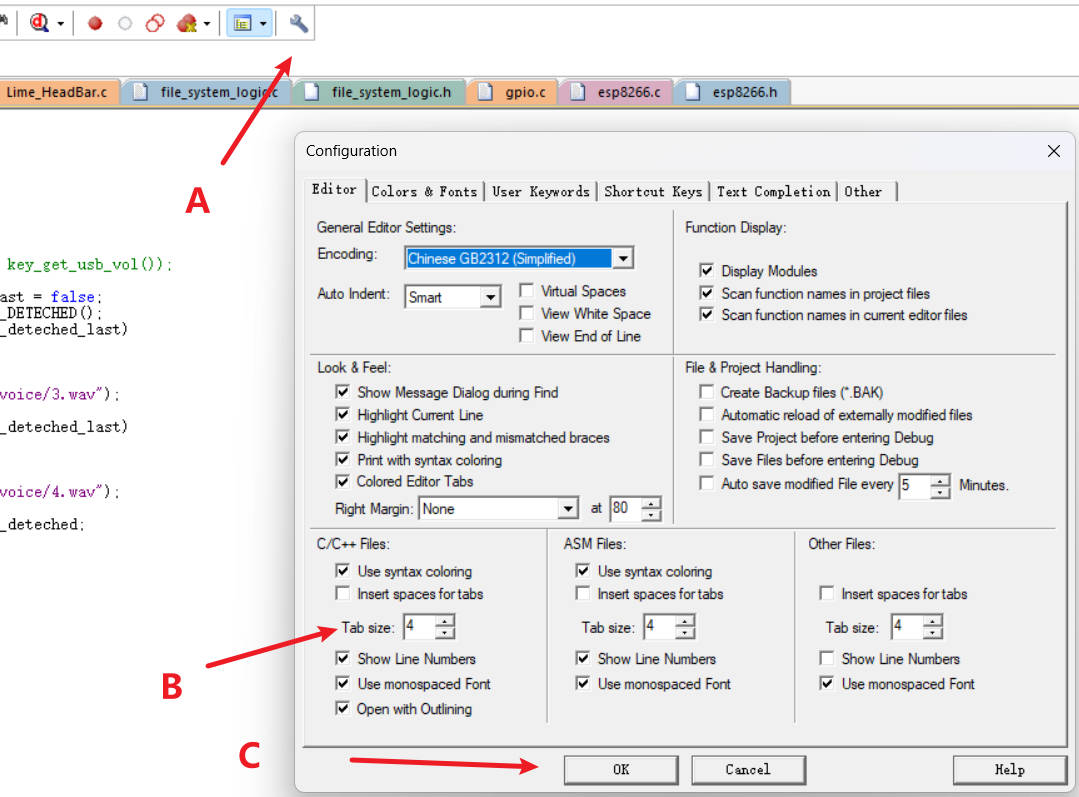
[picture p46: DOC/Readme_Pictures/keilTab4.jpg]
keil_set_tab_4


# 启动流程
1. 上电，运行bootloader程序
2. bootloader中尝试挂载文件系统，如果成功，则尝试读取更新固件
    - 如果没有更新固件，则校验已有固件，并跳转运行
    - 如果有更新固件，则下载更新固件，校验后覆盖已有固件，并跳转运行
    - 如果上述任意一步出错，则重建当前文件系统，尝试挂载成功后，开启USB并进入U盘模式，等待用户更新固件
3. 运行应用程序固件，启动wifi连接，连接成功后，尝试连接天气API，获取天气信息，并显示在屏幕上

# 固件更新说明
具体流程推荐详细阅读RELEASE_FIRMWARE文件夹中的README.md文件

概述：
进入U盘模式后，可直接将已签名的待更新固件bin文件复制到U盘，复制完成后，断电，重新上电，杯垫亮黄灯，等待固件更新完成。
更新完成后，杯垫亮绿灯，此时会自动跳转固件并执行

# 版权
bilibili 平韵の小窝 原创作品

仅限个人学习使用，严禁无授权的商业用途！

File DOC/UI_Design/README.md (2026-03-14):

# 文件夹概览

- black: 黑色主题的天气图片素材
- white: 白色主题的天气图片素材
- pic_resource: 其它图片素材资源文件夹
- 其余PSD文件：使用Photoshop设计的UI素材文件

# 版权
- black 和 white 图片素材来源于心知天气官网，版权归属于心知天气
- 其余图片素材为AI大模型创作
- UI界面为作者自己的创意，版权归属于作者所有

仅限个人学习使用，严禁无授权的商业用途！

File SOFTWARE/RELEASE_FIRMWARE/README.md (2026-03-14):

# 固件说明

> 以下所有应用程序均已签名，可被bootloader识别并自动更新

## V2.1固件列表：
> 初版，实现bootloader + application分离，实现自动更新功能

- F405_CUP_MAT_Bootloader.hex：提醒喝水杯垫F405主板引导程序
- F405_CUP_MAT_V2_Debug.bin：提醒喝水杯垫F405主板应用程序，包含调试信息，修改名字为update.bin后，粘贴入U盘，可被bootloader识别并自动更新
- F405_CUP_MAT_V2_Debug.hex：提醒喝水杯垫F405主板应用程序，包含调试信息
- F405_CUP_MAT_V2_Release.bin：提醒喝水杯垫F405主板应用程序，无调试信息，修改名字为update.bin后，粘贴入U盘，可被bootloader识别并自动更新
- F405_CUP_MAT_V2_Release.hex：提醒喝水杯垫F405主板应用程序，无调试信息
- F405_Release_Merged.hex：合并固件文件，包含提醒喝水杯垫F405主板应用程序和引导程序，用于工厂批量生产

## V2.0固件列表：
> 基础版本，无bootloader，已弃用

# 更新固件方法：
## 自动更新（V2.1及以上版本）：

> 注意！只适用于目前运行V2.1及以上版本固件的杯垫，如果您的杯垫目前运行V2.0版本，则需要手动更新固件

固件类型说明：
U盘自动更新只支持后缀为.bin的文件，类型包含两种，分别为Debug版和Release版。

- F405_CUP_MAT_V2_Debug.bin：包含调试信息（包含屏幕帧率，CPU占用率，串口日志等，可能会轻微影响性能，仅供调试使用）
- F405_CUP_MAT_V2_Release.bin：无调试信息（日常使用版）

自动更新流程：

1. 寻找心仪的固件（固件列表里后缀为.bin的文件，若您的电脑未显示文件后缀，请查看本文结尾），将其改名为update.bin，并记住位置 
2. 进入U盘模式，将需要更新的固件文件（update.bin）放入U盘根目录，待传输完成后，弹出U盘
3. 为系统重新上电，等待左上角LED灯点亮
4. 若LED为黄色，则成功识别到待更新固件，并开始尝试更新
5. 若更新成功，则LED灯变绿色，之后系统会自动运行新固件

## 手动更新（设备变砖了，或从旧V2.0版本升级到V2.1）：
如果设备更新失败，LED指示灯亮红灯，且无法进入U盘模式，则需要手动更新固件。
可参考最外层手册，3.5章节，为STM32烧录固件。
> 该方案最为稳定，也是最推荐的方案，但是需要额外准备一个ST-Link调试器。

连接ST-Link SWD接口到PCB板，推荐按如下方式接线：

左侧为ST-Link接口，右侧为PCB接口：
- 3V3   <---> 3V3
- SWCLK <---> SCK
- GND   <---> GND
- SWDIO <---> SDA
- RESET <---> RST

同时，建议断开USB供电，全板仅通过ST-Link提供STM32F4所需的3.3V电源

完成连接后，将ST-Link插入电脑，打开STM32CubeProgrammer软件，选择ST-Link模式，点击Connect按钮，选择下载的固件文件，点击Program按钮，等待下载完成。

# 附录
## 如何查看当前运行的固件版本
在杯垫设置页面最后一页（关于页面）右侧，有软件版本，后接版本号为当前运行的版本。

<!-- 这是一张图片，ocr 内容为： -->


## 如何让电脑显示文件扩展名
> 适用于win10和win11系统

<!-- 这是一张图片，ocr 内容为： -->


然后打开固件目录，就可以看到文件拓展名了:

<!-- 这是一张图片，ocr 内容为： -->


# 版权
bilibili 平韵の小窝 原创作品

仅限个人学习使用，严禁无授权的商业用途！

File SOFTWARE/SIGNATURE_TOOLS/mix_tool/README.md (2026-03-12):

# 功能介绍
这是一个基于python的hex合并工具，用于将bootloader和app合并成一个完整的hex文件，以便工厂批量烧录
# 如何使用

## 环境搭建
本项目需使用python环境，需确保安装，同时需要安装IntelHex库，使用如下命令安装：
```
pip install intelhex
```

## 如何使用
将待合并的bootloader和app分别编译成hex文件，并放到./input目录下，然后双击批处理脚本运行，即可生成合并后的hex文件，并输出到./output目录下

# 版权
bilibili 平韵の小窝 原创作品

仅限个人学习使用，严禁无授权的商业用途！

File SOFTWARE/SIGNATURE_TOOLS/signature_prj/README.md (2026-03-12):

# 功能介绍
一个简单的签名工具，用于为提醒喝水杯垫的APP固件进行签名，以便被bootloader自动识别并校验更新固件。
# 如何使用

## 环境搭建
本项目需使用cmake构建，请确保系统中已安装cmake

测试方法

```
cmake --version
```
如果输出信息如下：
```
cmake version 3.31.0-rc3

CMake suite maintained and supported by Kitware (kitware.com/cmake).
```
表示CMake环境正常

测试make环境
```
make --version
```
如果输出信息如下：
```
GNU Make 4.4.1
Built for x86_64-w64-mingw32
Copyright (C) 1988-2023 Free Software Foundation, Inc.
License GPLv3+: GNU GPL version 3 or later <https://gnu.org/licenses/gpl.html>
This is free software: you are free to change and redistribute it.
There is NO WARRANTY, to the extent permitted by law.
```
表示make环境正常
## 编译工程
使用VSCode打开工程
安装C/C++扩展，并配置好编译环境

右键CMakeLists.txt，选择清理所有项目并重新配置

点击VSCode左下角的三角按钮，开始编译并运行

## 效果
编译成功后，在build目录下生成签名工具exe可执行文件，可通过命令行测试该工具

# 版权
bilibili 平韵の小窝 原创作品

仅限个人学习使用，严禁无授权的商业用途！

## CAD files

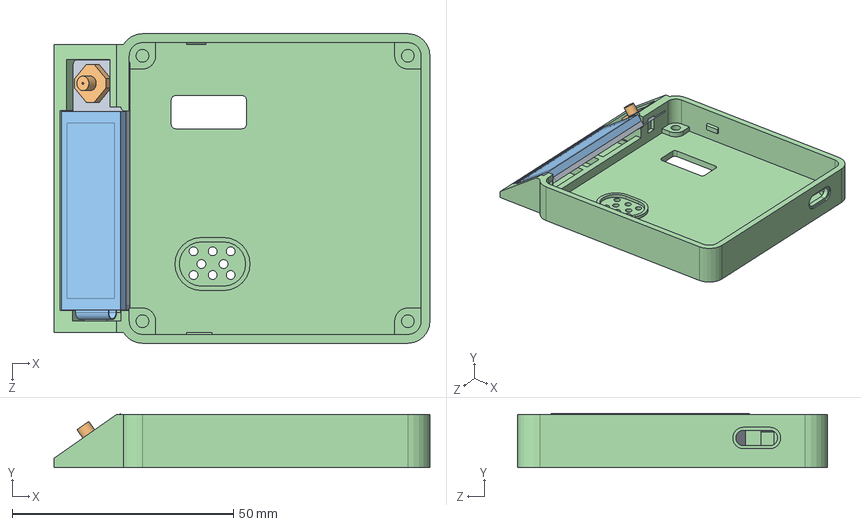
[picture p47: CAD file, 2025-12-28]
STRUCTOR/装配体.SLDASM
85.0 x 12.2 x 70.0 mm
底壳
屏幕3D建模
五向摇杆
屏幕PCB定位模

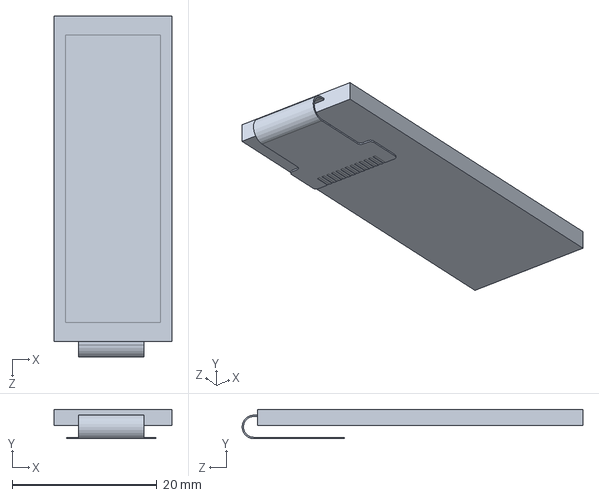
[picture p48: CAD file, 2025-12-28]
STRUCTOR/成品零件/屏幕3D建模.SLDPRT
16.3 x 4.07 x 47.1 mm

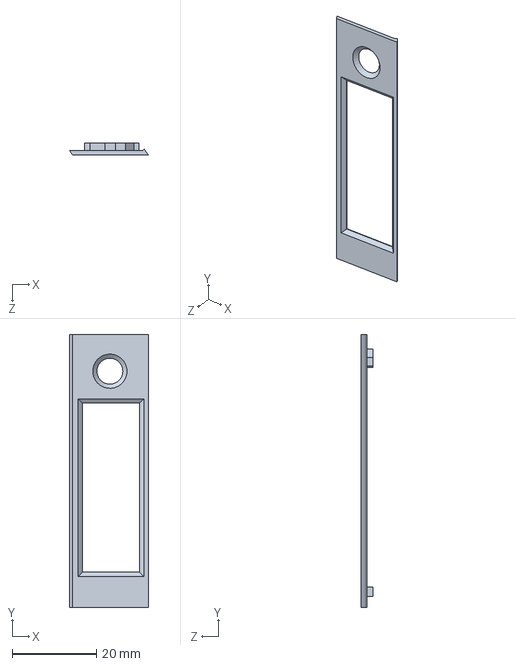
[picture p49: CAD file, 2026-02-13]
STRUCTOR/打印件/面板.SLDPRT
18.8 x 65.0 x 2.80 mm

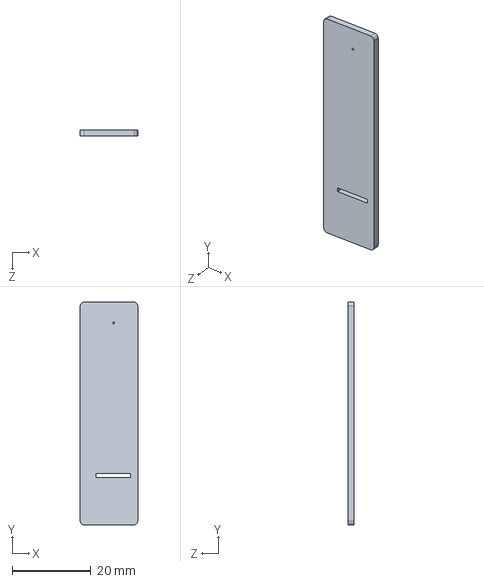
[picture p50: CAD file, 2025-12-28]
STRUCTOR/PCB/屏幕PCB定位模.SLDPRT
14.6 x 56.6 x 1.60 mm

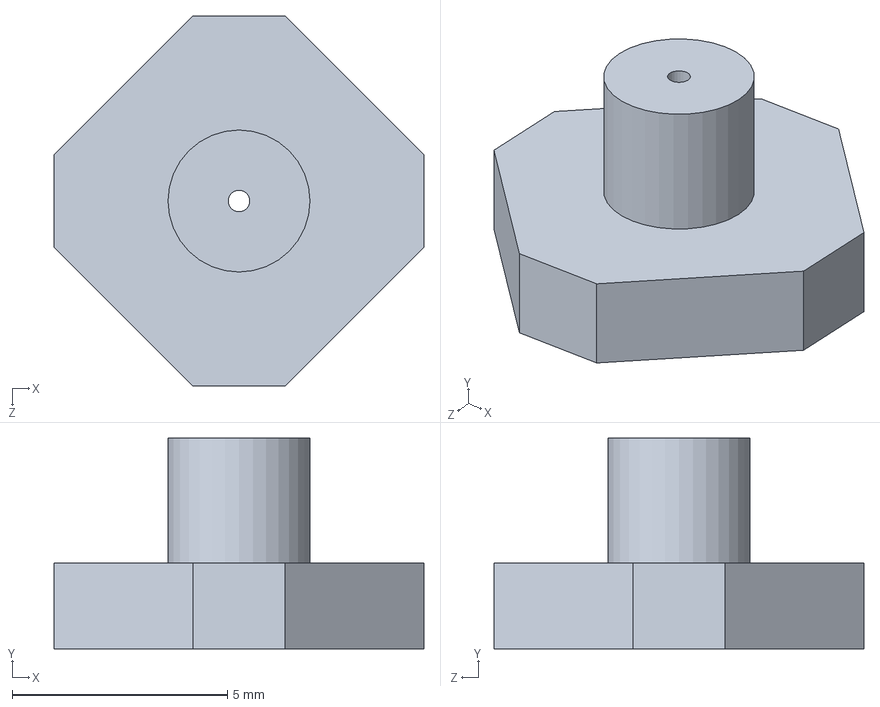
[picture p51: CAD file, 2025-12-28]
STRUCTOR/成品零件/五向摇杆.SLDPRT
8.60 x 4.90 x 8.60 mm

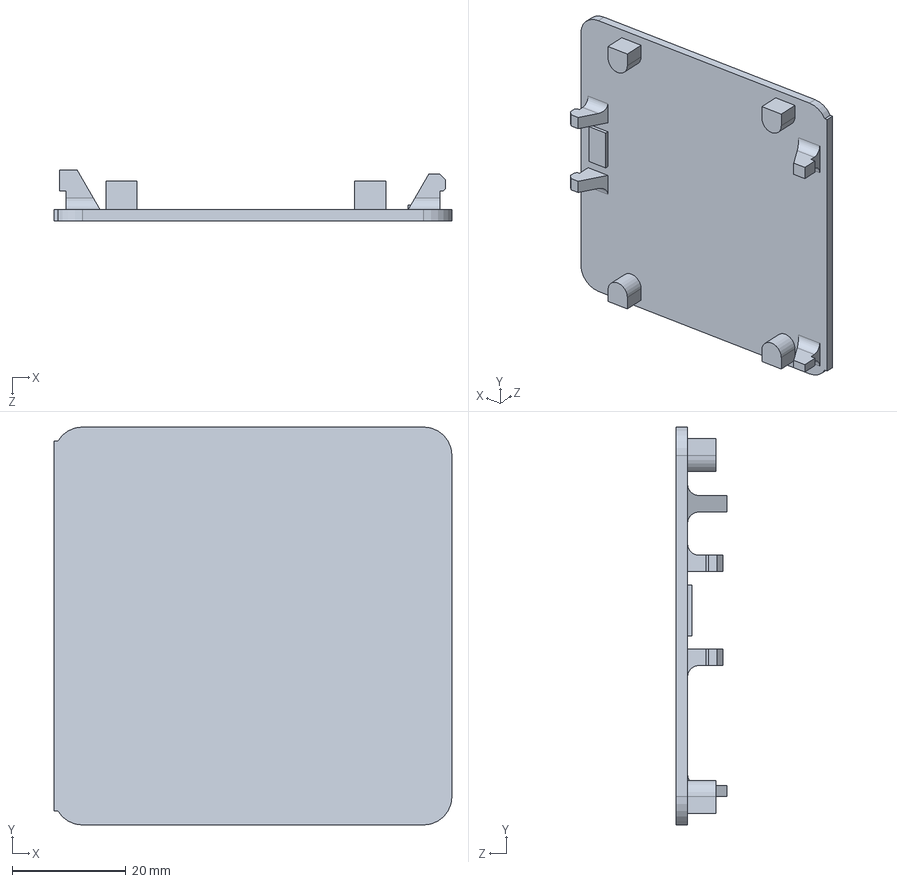
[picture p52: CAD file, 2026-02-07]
STRUCTOR/打印件/顶盖.SLDPRT
70.0 x 70.0 x 8.90 mm

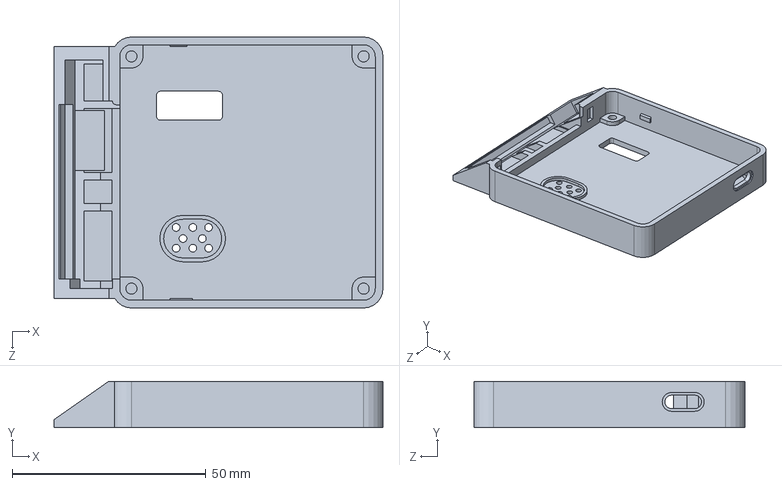
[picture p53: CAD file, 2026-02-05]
STRUCTOR/打印件/底壳.SLDPRT
85.0 x 12.0 x 70.0 mm

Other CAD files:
STRUCTOR/PCB/主PCB定位模型.SLDPRT
STRUCTOR/PCB/主PCB定位模型.DXF
STRUCTOR/PCB/屏幕PCB定位模.DXF
STRUCTOR/打印件/底壳.3MF
STRUCTOR/打印件/面板.3MF
STRUCTOR/打印件/顶盖.3MF

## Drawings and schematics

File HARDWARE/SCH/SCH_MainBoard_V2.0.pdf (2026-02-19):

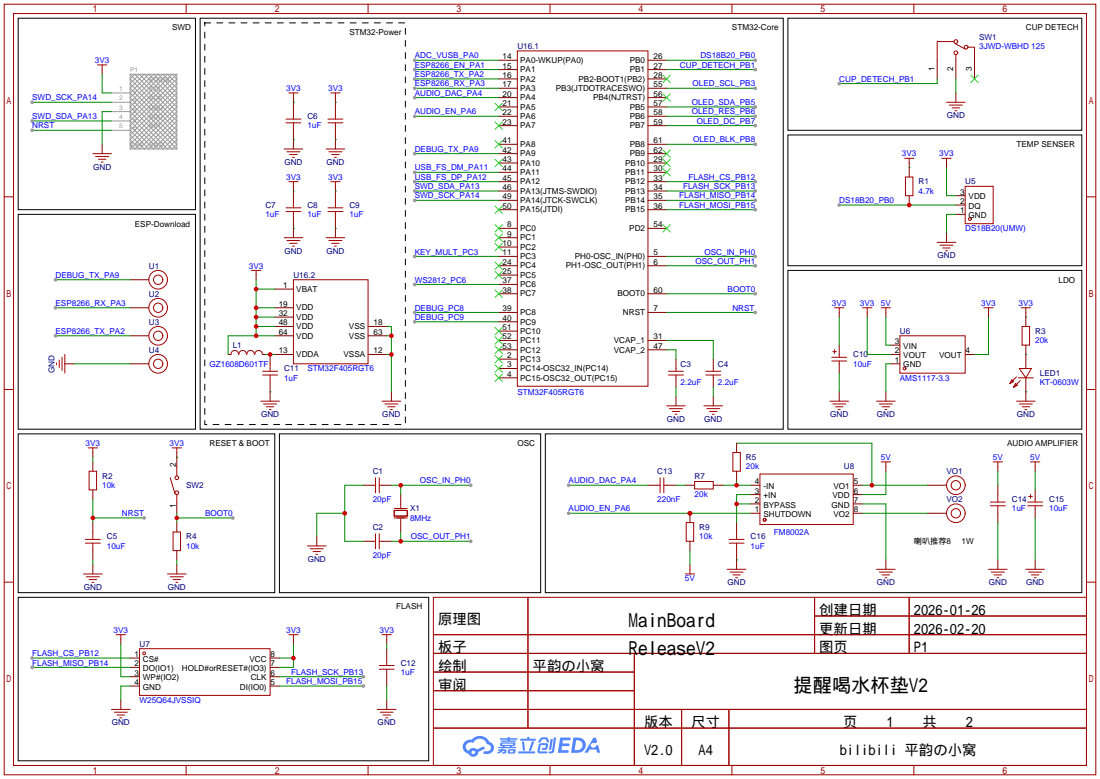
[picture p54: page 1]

原理图 | MainBoard | 创建日期 | 2026-01-26
板子 | ReleaseV2 | 图页 | P1
绘制 | 平韵の小窝 | 提醒喝水杯垫V2
审阅

更新日期 | 2026-02-20

V2.0 | A4 | bilibili 平韵の小窝

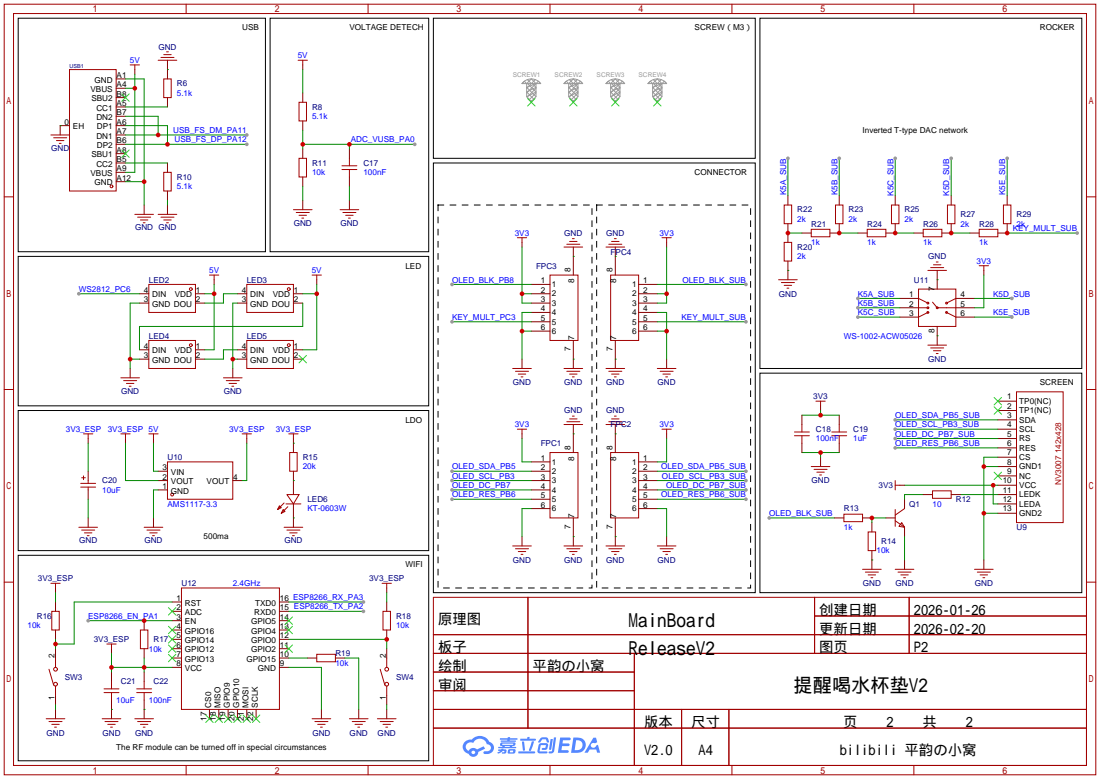
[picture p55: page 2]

Inverted T-type DAC network

原理图 | MainBoard | 创建日期 | 2026-01-26
板子 | ReleaseV2 | 图页 | P2
绘制 | 平韵の小窝 | 提醒喝水杯垫V2
审阅

更新日期 | 2026-02-20

The RF module can be turned off in special circumstances

V2.0 | A4 | bilibili 平韵の小窝

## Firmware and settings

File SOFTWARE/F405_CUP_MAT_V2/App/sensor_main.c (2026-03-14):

#include "sensor_main.h"
#include "cmsis_os.h"

#include "ws2812.h"
#include "ds18b20.h"
#include "key.h"
#include "spi_flash.h"
#include "rtc_time.h"
#include "ff.h"
#include "esp8266.h"
#include "rgbled_logic.h"
#include "lcd_init.h"

/* just test */
#include "file_system_logic.h"

#include "audio_player.h"
#include "audio_call_logic.h"
#include "Lime_App_Hal.h"
#include "stm_system_io.h"
#include "audio_main.h"

static void senser_task_error_handle(void);
static void read_sync_setting_info(void);
static void ds18b20_scan_handle(void);
static void play_flash_music_handle(void);
static void time_logic_handle(void);
static void volume_sync_handle(void);
static void cup_scan_handle(void);
static void rgb_led_run_handle(void);
static void sleep_mode_handle(void);
static void audio_logic_handle(void);
static void restore_mode_detech(void);

void sensor_main(void const * argument)
{
	DEBUG_LOG("Task %s,start\n", __FUNCTION__);
	
	osDelay(1000);
	LimeRtc_SetNowTime(12, 30, 0);
	
	/* mount fatfs */
	LimeHAL_SetInitStep(10, "flash");
	if(file_system_Init() != HAL_OK)
	{
		DEBUG_LOG("file system init failed\n");
		
		/* show UI */
		LimeHAL_SetInitStep(11, "flash - failed!");
		
		/* enter error handle */
		senser_task_error_handle();
	}
	LimeHAL_SetFlashID(spi_flash_get_jedec_id());
	
	/* FatFs mount success, notify audio task */
	audio_main_task_yleld_exHook(false);
	
	osDelay(100);
	
	/* confirm necessery files */
	LimeHAL_SetInitStep(20, "file system");
	if(file_system_confirm() != HAL_OK)
	{
		DEBUG_LOG("resources confirm failed\n");
		
		/* show UI */
		LimeHAL_SetInitStep(21, "file system confirm failed!");
		
		osDelay(500);
		
		/* enter error handle */
		LimeHAL_SetFileSystemErr();
		while(1)
		{
			osDelay(100);
		}
	}
	
	osDelay(100);
	
	/* read setting.txt */
	LimeHAL_SetInitStep(30, "file system");
	read_sync_setting_info();
	
	osDelay(100);
	
	/* init ws2812 */
	LimeHAL_SetInitStep(40, "rgb led");
	ws2812_Init();
	
	/* init ds18b20 */
	LimeHAL_SetInitStep(50, "temperature senser");
	while(ds18b20_Init())
	{
		static uint8_t err_cnt = 0;
		DEBUG_LOG("ds18b20 init err\n");
		HAL_Delay(300);
		
		err_cnt ++;
		
		LimeHAL_SetInitStep(50 + err_cnt * 2, "temperature senser");
		
		if(err_cnt > 5)
		{
			LimeHAL_SetInitStep(59, "temperature senser failed!");
			osDelay(1000);
		}
	}
	
	osDelay(100);
	
	/* init ESP8266 */
	LimeHAL_SetInitStep(70, "ESP8266");
	if(esp8266_Init(1000) != HAL_OK)
	{
		DEBUG_LOG("ESP8266 init failed\n");
		
		LimeHAL_SetInitStep(71, "ESP8266 offline");
		
		osDelay(1000);
	}
	
	osDelay(100);
	
	LimeHAL_SetInitStep(100, "finish");
	
	osDelay(1000);
	
	while(1)
	{
		esp8266_sync_handle();
		
		ds18b20_scan_handle();
		
		play_flash_music_handle();
		
		time_logic_handle();
		
		volume_sync_handle();
		
		cup_scan_handle();
		
		rgb_led_run_handle();
		
		sleep_mode_handle();

		audio_logic_handle();
		
		restore_mode_detech();
		
		osDelay(10);
	}
}

static void ds18b20_scan_handle(void)
{
	/* limit frequence */
	static uint32_t last_run_time = 0;
	if((HAL_GetTick() - last_run_time < 200) && (HAL_GetTick() > 1500))
	{
		return;
	}
	last_run_time = HAL_GetTick();
	
	/* suspend tasks */
	vTaskSuspendAll();
	
	/* get DS28B20 Temper */
	int16_t ds18b20_raw = ds18b20_get_temp();
	float home_temp = ds18b20_raw / 10.0f;
	
	/* sync to lvgl hal */
	LimeHAL_SetHomeTemerSensor(home_temp);
	
	/* resume tasks */
	if( !xTaskResumeAll())
	{
		taskYIELD();
	}
}

static void read_sync_setting_info(void)
{
	/* malloc buffer */
	setting_file_info_t *info = pvPortMalloc(sizeof(setting_file_info_t));
	if(info == NULL)
	{
		DEBUG_LOG("malloc Failed\n");
		
		goto fill_default;
	}
	
	/* read para from setting.txt */
	if(file_system_read_setting_file(info) != HAL_OK)
	{
		vPortFree(info);
		
		goto fill_default;
	}
	
	/* setting para */
	DEBUG_LOG("readed setting.txt para:\n");
	DEBUG_LOG("wifi_name:%s\n", info->wifi_name);
	DEBUG_LOG("wifi_password:%s\n", info->wifi_password);
	DEBUG_LOG("city_name:%s\n", info->city_name);
	esp8266_set_wifi_info(info->wifi_name, info->wifi_password);
	esp8266_set_position(info->city_name);
	
	/* free buffer */
	vPortFree(info);
	
	return;
	
fill_default:
	DEBUG_LOG("fill default para:\n");
	DEBUG_LOG("wifi_name:%s\n", GLOBAL_DEFAULT_WIFI_NAME);
	DEBUG_LOG("wifi_password:%s\n", GLOBAL_DEFAULT_WIFI_PASSWORD);
	DEBUG_LOG("city_name:%s\n", GLOBAL_DEFAULT_CITY_NAME);
	esp8266_set_wifi_info(GLOBAL_DEFAULT_WIFI_NAME, GLOBAL_DEFAULT_WIFI_PASSWORD);
	esp8266_set_position(GLOBAL_DEFAULT_CITY_NAME);
}

static void play_flash_music_handle(void)
{
	/* no need play music */
	if( !LimeHAL_IsNeed_PlayMusic())
		return;
	
	/* get music index */
	uint8_t index = LimeHAL_GetPlayMusicIndex();

	auido_call_add_new_music_to_list(index, true);
}

static void time_logic_handle(void)
{
	static uint32_t last_run_time = 0;
	if(HAL_GetTick() - last_run_time < 1000)
		return;
	last_run_time = HAL_GetTick();
	
	/* get now time from RTC */
	volatile uint8_t hour = 0, minute = 0, second = 0;
	LimeRtc_GetNowTime((uint8_t*)&hour, (uint8_t*)&minute, (uint8_t*)&second);
	
	/* sync time to GUI */
	LimeHAL_SetTime(hour, minute);
}

static void cup_scan_handle(void)
{
	static bool is_countdown = false;
	static bool is_timeout = false;
	uint32_t timeout_second = 0;
	
	/* get setted info */
	uint8_t timeout_index = LimeHAL_GetCountDownTimeIndex();
	switch(timeout_index)
	{
		case 1:
			timeout_second = 1 * 60;
			break;
		case 2:
			timeout_second = 5 * 60;
			break;
		case 3:
			timeout_second = 10 * 60;
			break;
		case 4:
			timeout_second = 25 * 60;
			break;
		case 5:
			timeout_second = 45 * 60;
			break;
		case 6:
			timeout_second = 60 * 60;
			break;
		default:
			timeout_second = 120 * 60;
			DEBUG_LOG("timeout_index:%d,err\n", timeout_index);
			break;
	}
	
	/* cup status detech */
	static bool is_cup_deteched_last = false;
	bool is_cup_deteched = IS_CUP_DETECHED();
	
	/* cup senser is pressed */
	if(is_cup_deteched && !is_cup_deteched_last)
	{
		LimeHAL_SettingInfo_PlayMusicByIndex(2);
		LimeRtc_SetSoftAlarm(timeout_second);
		is_timeout = false;
	}
	
	/* cup senser is released */
	if(!is_cup_deteched && is_cup_deteched_last)
	{
		LimeHAL_SettingInfo_PlayMusicByIndex(4);
	}
	is_cup_deteched_last = is_cup_deteched;
	
	/* timeout check */
	int32_t elaps_time_seconds = LimeRtc_GetSoftAlarm_LastTime();
	if(is_cup_deteched)
	{
		/* no timeout */
		if(elaps_time_seconds >= 0)
		{
			LimeHAL_SetWorkingStatus(LimeHal_WoringStatus_Countdown);
			LimeHAL_SetRemainCountSeconds(elaps_time_seconds);
		}
		
		/* timeout */
		else
		{
			LimeHAL_SetWorkingStatus(LimeHal_WoringStatus_CountFinish);
			LimeHAL_SetRemainCountSeconds(0);
			if( !is_timeout)
			{
				is_timeout = true;
				LimeHAL_SettingInfo_PlayMusicByIndex(3);
			}
		}
	}
	else
	{
		LimeHAL_SetWorkingStatus(LimeHal_WoringStatus_Idle);
		LimeHAL_SetRemainCountSeconds(timeout_second);
	}
	
	LimeHAL_SetTotalCountSeconds(timeout_second);
}

void senser_main_set_now_time_hook(uint8_t hour, uint8_t minute, uint8_t second)
{
	LimeRtc_SetNowTime(hour, minute, second);
}

static void volume_sync_handle(void)
{
	uint8_t volume_setted = LimeHAL_GetVolume();
	
	/* 0:off, 1:low, 2:mid, 3:high */
	switch(volume_setted)
	{
		case 0:
			volume_setted = 0;
			break;
		case 1:
			volume_setted = 160;
			break;
		case 2:
			volume_setted = 220;
			break;
		case 3:
			volume_setted = 255;
			break;
		default:
			volume_setted = 255;
			break;
	}
	Lime_audio_play_set_volume(volume_setted);
}

static void rgb_led_run_handle(void)
{
	/* get GUI setted value */
	uint8_t led_brightness = LimeHAL_GetLumen();
	uint8_t mode = LimeHAL_GetLightMode();
	
	/* get now led mode */
	rgbled_mode_e led_mode = rgbled_mode_off;
	switch(mode)
	{
		case 0:
			led_mode = rgbled_mode_rainbow;
			break;
		case 1:
			led_mode = rgbled_mode_candle;
			break;
		case 2:
			led_mode = rgbled_mode_starnight;
			break;
		case 3:
			led_mode = rgbled_mode_white;
			break;
		default:
			led_mode = rgbled_mode_off;
			break;
	}
	
	/* get now led brightness */
	switch(led_brightness)
	{
		case 0:
			led_brightness = 0;
			led_mode = rgbled_mode_off;
			break;
		case 1:
			led_brightness = 10;
			break;
		case 2:
			led_brightness = 20;
			break;
		case 3:
			led_brightness = 36;
			break;
		default:
			led_brightness = 4;
			break;
	}
	
	/* starnight mode, inc brightness */
	led_brightness = (led_mode == rgbled_mode_starnight) ? led_brightness + 20 : led_brightness;
	
	/* sync to low driver */
	rgbled_set_mode(led_mode);
	rgbled_set_brightness(led_brightness);
	
	/* led run handle */
	rgbled_run_handler();
}

static void sleep_mode_handle(void)
{
	/* wait 1s */
	static uint32_t last_run_time = 0;
	if(HAL_GetTick() - last_run_time < 1000)
		return;
	last_run_time = HAL_GetTick();
	
	/* get now time */
	uint8_t now_hour = 0, now_minutes = 0, now_seconds = 0;
	LimeRtc_GetNowTime(&now_hour, &now_minutes, &now_seconds);
	
	/* if night */
	bool is_night = false;
	if((now_hour > 23) || (now_hour < 7))
	{
		is_night = true;
	}
	
	/* sync data to HAL */
	LimeHAL_SetSleepMode(is_night);
	
	/* when night & no cup, make screen backlight low */
	bool is_idle = LimeHAL_WorkingStatus_IsIdle();
	PY_LCD_SetBackLight((is_night && is_idle) ? 15 : 90);
	
	/* when night, make led low */
	rgbled_set_night_mode(is_night);
}

static void audio_logic_handle(void)
{
	/* sync data from HAL */
	const LimeHal_Info_t *info = LimeHAL_GetInfoPin();
	bool server_connected = info->senserInfo.isWeatherDataValid;
	uint8_t hour = info->senserInfo.hour;
	uint8_t weather_code = info->senserInfo.todayWeather.weatherLogoID;

	/* sync data to audio call logic */
	if(server_connected)
	{
		audio_call_logic_sync_time(hour);
		audio_call_logic_sync_weather(weather_code);
	}
	audio_call_logic_sync_server(server_connected);

	/* audio logic handle */
	audio_call_logic_handle();
}

static void restore_mode_detech(void)
{
	if( !LimeHAL_IsSetted_RestoreMode())
		return;
	
	/* suspend audio_task */
	audio_main_task_suspend();
	
	/* restore filesystem, then re-start system */
	lime_stm_system_restore();
}

static void senser_task_error_handle(void)
{
	DEBUG_LOG("%s()\n", __FUNCTION__);
	
	while(1)
	{
		osDelay(1000);
	}
}

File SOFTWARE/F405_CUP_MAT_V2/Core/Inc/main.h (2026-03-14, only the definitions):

#define KEY_MULT_Pin GPIO_PIN_3
#define KEY_MULT_GPIO_Port GPIOC
#define ESP8266_EN_Pin GPIO_PIN_1
#define ESP8266_EN_GPIO_Port GPIOA
#define AUDIO_EN_Pin GPIO_PIN_6
#define AUDIO_EN_GPIO_Port GPIOA
#define DS18B20_Pin GPIO_PIN_0
#define DS18B20_GPIO_Port GPIOB
#define CUP_DETECH_Pin GPIO_PIN_1
#define CUP_DETECH_GPIO_Port GPIOB
#define FLASH_CS_Pin GPIO_PIN_12
#define FLASH_CS_GPIO_Port GPIOB
#define WS2812_Pin GPIO_PIN_6
#define WS2812_GPIO_Port GPIOC
#define DEBUG_PC8_Pin GPIO_PIN_8
#define DEBUG_PC8_GPIO_Port GPIOC
#define DEBUG_PC9_Pin GPIO_PIN_9
#define DEBUG_PC9_GPIO_Port GPIOC
#define OLED_RES_Pin GPIO_PIN_6
#define OLED_RES_GPIO_Port GPIOB
#define OLED_DC_Pin GPIO_PIN_7
#define OLED_DC_GPIO_Port GPIOB
#define OLED_BLK_Pin GPIO_PIN_8
#define OLED_BLK_GPIO_Port GPIOB
#define SOFTWARE_VERSION	"V2.1 DEBUG"
#define SOFTWARE_VERSION	"V2.1"
#define GLOBAL_SETTING_FILE_PATH		"D:/setting.txt"
#define GLOBAL_DEFAULT_WIFI_NAME		"wifi_name"
#define GLOBAL_DEFAULT_WIFI_PASSWORD	"wifi_passord"
#define GLOBAL_DEFAULT_CITY_NAME		"BeiJing"

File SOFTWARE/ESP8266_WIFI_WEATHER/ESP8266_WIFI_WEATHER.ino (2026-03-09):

#include <ESP8266WiFi.h>
#include <ESP8266HTTPClient.h>
#include <WiFiClientSecure.h>
#include <ArduinoJson.h>
#include <WiFiUdp.h>
#include <NTPClient.h>

// ============ 用户配置区 ============
#define WEATHER_API_KEY ""  // 填入你申请的心知天气API密钥
// ===================================

String wifiName = "";
String wifiPassword = "";
bool wifiNameReceived = false;
bool wifiPasswordReceived = false;
const unsigned long WIFI_TIMEOUT = 30000;
String cityName = "";
bool cityNameReceived = false;

// NTP配置
WiFiUDP ntpUDP;
NTPClient timeClient(ntpUDP, "ntp1.aliyun.com", 8 * 3600, 60000);
// 参数说明：NTP服务器，时区偏移（秒），更新间隔（毫秒）

void waitForWiFiConfig(void);
void connectToWiFi();
void waitForPositionConfig(void);
void getTimeSimple(int &hour, int &minute);

void setup() {
  /* 初始化串口 */
  Serial.begin(9600);
  Serial.println("\n\n---Lime ESP8266 wifi weather kit start...");
  Serial.println("---version:1.0.0");
  Serial.println("---CompiledTime:" + String(__DATE__) + " at " + String(__TIME__));

  /* 等待通过串口获取位置信息 */
  waitForPositionConfig();
    
  /* 等待通过串口获取wifi信息 */
  waitForWiFiConfig();

  /* 尝试连接wifi */
  connectToWiFi();

  /* 首次获取时间 */
  timeClient.begin();
  fetchCurrentTime();
  
  /* 首次获取天气 */
  fetchCurrentWeather();  // 当前天气
  fetchDailyWeather();    // 未来天气
}

void loop() {
  if (Serial.available() > 0) {
    String input = Serial.readStringUntil('\n');
    input.trim(); // 去除首尾空白字符
    
    if (input.equals("set_refreshnow")) {
      Serial.println("Weather refresh command received, starting refresh...");

      fetchCurrentTime();     // 当前时间
      fetchCurrentWeather();  // 当前天气
      fetchDailyWeather();    // 未来天气
    }
  }
  
  
  delay(1000);
}

// 获取当前实时时间
void fetchCurrentTime() {
  timeClient.update();
  String formattedTime = timeClient.getFormattedTime();
  Serial.print("---nowtime:");
  Serial.println(formattedTime);
}

// 获取当前实时天气
void fetchCurrentWeather() {
  if (WiFi.status() != WL_CONNECTED) {
    Serial.println("WiFi not connected");
    return;
  }

  String url = "https://api.seniverse.com/v3/weather/now.json?key=" + 
               String(WEATHER_API_KEY) + "&location=" + cityName + "&language=zh-Hans&unit=c";

  WiFiClientSecure client;
  client.setInsecure();
  
  HTTPClient http;
  http.begin(client, url);
  int httpCode = http.GET();
  
  if (httpCode == 200) {
    String payload = http.getString();
    
    DynamicJsonDocument doc(1024);
    DeserializationError error = deserializeJson(doc, payload);
    
    if (!error) {
      JsonObject results0 = doc["results"][0];
      JsonObject location = results0["location"];
      JsonObject now = results0["now"];
      
      // 从JSON中提取实际存在的字段
      String cityName = location["name"].as<String>();
      String weatherText = now["text"].as<String>();
      String temperature = now["temperature"].as<String>();
      String updateTime = results0["last_update"].as<String>();
      
      Serial.println("=== Current Weather Details ===");
      Serial.println("---City:" + cityName);
//      Serial.println("---Weather:" + weatherText);
      Serial.println("---Temperature:" + temperature);
      
      // 只打印JSON中实际存在的字段
      if (now.containsKey("feels_like")) {
        String feelsLike = now["feels_like"].as<String>();
        Serial.println("Feels Like: " + feelsLike + "℃");
      }
      
      if (now.containsKey("humidity")) {
        String humidity = now["humidity"].as<String>();
        Serial.println("Humidity: " + humidity + "%");
      }
      
      if (now.containsKey("wind_direction")) {
        String windDirection = now["wind_direction"].as<String>();
        Serial.println("Wind Direction: " + windDirection);
      }
      
      if (now.containsKey("wind_scale")) {
        String windScale = now["wind_scale"].as<String>();
        Serial.println("Wind Scale: " + windScale + "级");
      }
      
      if (now.containsKey("visibility")) {
        String visibility = now["visibility"].as<String>();
        Serial.println("Visibility: " + visibility + "km");
      }
      
      if (now.containsKey("pressure")) {
        String pressure = now["pressure"].as<String>();
        Serial.println("Pressure: " + pressure + "hPa");
      }
      
      Serial.println("Update Time: " + updateTime);
    } else {
      Serial.println("JSON Parsing Error");
    }
  } else {
    Serial.println("HTTP Request Failed: " + String(httpCode));

    Serial.println("Daily weather HTTP request failed: " + String(httpCode));
    String payload = http.getString();
    
    DynamicJsonDocument doc(2048);
    DeserializationError error = deserializeJson(doc, payload);

    Serial.println("Payload:3");
    Serial.println(payload);
  }
  
  http.end();
}

// 获取未来3天天气预报
void fetchDailyWeather() {
  if (WiFi.status() != WL_CONNECTED) {
    Serial.println("WiFi not connected");
    return;
  }

  String url = "https://api.seniverse.com/v3/weather/daily.json?key=" + 
               String(WEATHER_API_KEY) + "&location=" + cityName + "&language=zh-Hans&unit=c&start=0&days=3";

  WiFiClientSecure client;
  client.setInsecure();
  
  HTTPClient http;
  http.begin(client, url);
  int httpCode = http.GET();
  
  if (httpCode == 200) {
    String payload = http.getString();
    
    DynamicJsonDocument doc(2048);
    DeserializationError error = deserializeJson(doc, payload);

//    Serial.println("Payload:2");
//    Serial.println(payload);
    
    if (!error) {
      JsonArray daily = doc["results"][0]["daily"];
      
      Serial.println("=== 3-Day Weather Forecast ===");
    
      for (int i = 0; i < daily.size(); i++) {
        JsonObject day = daily[i];
        
        // 检查并提取实际存在的字段
        if (day.containsKey("date")) {
          Serial.println("---Date: " + day["date"].as<String>());
        }

        if (day.containsKey("code_day")) {
          Serial.println("---code_day:" + day["code_day"].as<String>() + "");
        }
        
        if (day.containsKey("text_day")) {
          Serial.println("---Day:" + day["text_day"].as<String>());
        }
        
//        if (day.containsKey("text_night")) {
//          Serial.println("---Night: " + day["text_night"].as<String>());
//        }
        
        if (day.containsKey("high") && day.containsKey("low")) {
          Serial.println("---TemperatureLow:" + day["low"].as<String>());
          Serial.println("---TemperatureHigh:" + day["high"].as<String>());
        } else if (day.containsKey("high")) {
          Serial.println("---TemperatureHigh:" + day["high"].as<String>());
        } else if (day.containsKey("low")) {
          Serial.println("---TemperatureLow:" + day["low"].as<String>());
        }
        
        if (day.containsKey("humidity")) {
          Serial.println("---Humidity:" + day["humidity"].as<String>());
        }
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

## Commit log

2025-12-29 update 3D
    [底壳.3MF, 底壳.SLDPRT]
2025-12-30 fix usb storage bugs
    [F405_CUP_MAT_V2.ioc, main.c]
2026-01-11 add animation to count GUI, fix interrupt anim bugs
    [Lime_LvMainFace.c, lcd_init.c]
2026-01-15 fix flash spi-dma driver bugs, Weather UI Performance Optimization
    [F405_CUP_MAT_V2.ioc, lcd_init.c, main.c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]
2026-01-18 link adckey driver
    [心知天气位置代码.xls]
2026-01-20 add ESP8266 drivers
2026-01-20 refresh ESP8266 driver, fix bugs
    [esp8266.c]
2026-01-25 add FatFs audio play, fix dac dma bugs
    [F405_CUP_MAT_V2.ioc, audio_player.c, esp8266.c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]
2026-01-26 link sensor info to lvgl hal
2026-01-28 fix voice decoder bugs, add volume calculation, add setting face(10%)
    [Lime_LvMainFace.c, audio_player.c]
2026-02-02 add setting sub ui 100%, fix U-Disk bugs, fix IP UI
    [sensor_main.c, spi_flash.c, stm_system_io.c]
2026-02-03 add RTC, add start UI, fix Weather UI load failed(case fatfs)
    [F405_CUP_MAT_V2.ioc, Lime_LvMainFace.c, esp8266.c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]
2026-02-03 fix RTC bugs(read data not refresh)
    [Lime_LvMainFace.c, rtc_time.c, sensor_main.c]
2026-02-05 add 3d module
    [底壳.3MF, 底壳.SLDPRT, 面板.SLDPRT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]
2026-02-07 fix 3D upper's height
    [底壳.3MF, 面板.3MF, 顶盖.3MF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]
2026-02-07 add error and warning messagebox
    [Lime_LvMainFace.c, key_main.c, sensor_main.c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]
2026-02-13 update 3D model
    [面板.3MF, 面板.SLDPRT]
2026-02-19 fix voice played failed, fix ws2812 blink, fix key with soft-filter
    [audio_player.c, key.c, key_main.c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]
2026-02-19 add hardware PCB, cutting lvgl lib
2026-02-19 add hardware schematic V2.0
2026-02-20 fix audio bugs 30%
    [audio_player.c, main.h, sensor_main.c]
2026-02-20 fix audio play bug 100%, add audio task
    [F405_CUP_MAT_V2.ioc, audio_player.c, main.h]
2026-02-21 fix countdown 5min bug
    [sensor_main.c]
2026-03-11 format dir, prepare to release
    [心知天气位置代码.xls]
2026-03-11 add release hex, fix compile time UI
    [main.c, main.h]
2026-03-11 fix PCB pic
2026-03-13 fix app resotre err bug, update bootloader,bin,hex,ect...
    [F405_CUP_MAT_V2.ioc, file_system_logic.c, key_main.c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]
2026-07-16 refactor: translate comments to English, clean up dead code, fix sscanf stack overflow in esp8266, and tune FatFs config
    [ds18b20.c, esp8266.c, lcd_init.c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]
2026-11-02 更新3D建模，优化装配公差
2026-11-07 fix: 天气页复位、WS2812 双缓冲同步、USB 电压新旧硬件自适应
    - 天气页离开时暂停刷新并隐藏所有外部 Flash 元素，重新进入时逐个加载，避免切页回来卡顿
    - WS2812 改为双缓冲，DMA 只读 raw 缓冲，定时器中断在空闲时提交新帧，消除任务与 DMA 抢同一缓冲导致的闪烁
    - USB 电压检测按 ADC 饱和自动识别新旧分压硬件，低压提示限制为 1 分钟最多一次
2026-11-07 chore: 版本号升至 V2.2，MDK-ARM 目录仅保留工程文件并忽略编译产物
    - .gitignore 对 SOFTWARE/F405_CUP_MAT_V2/MDK-ARM 采用反向白名单，仅保留 uvprojx/uvoptx/startup/分散加载文件
    - 忽略 build_log.txt、编译中间文件等产物

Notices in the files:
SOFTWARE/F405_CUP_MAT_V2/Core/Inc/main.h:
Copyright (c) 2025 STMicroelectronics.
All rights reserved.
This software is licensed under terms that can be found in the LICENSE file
